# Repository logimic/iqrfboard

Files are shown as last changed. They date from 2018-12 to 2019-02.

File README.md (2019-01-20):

# [IQRFBB-10 Development Board](http://logimic.com/iqrfboard)


<br>
<br>
<p align="right">Powered for you by <a href="http://www.logimic.com" align="right">logimic.com</a></p>

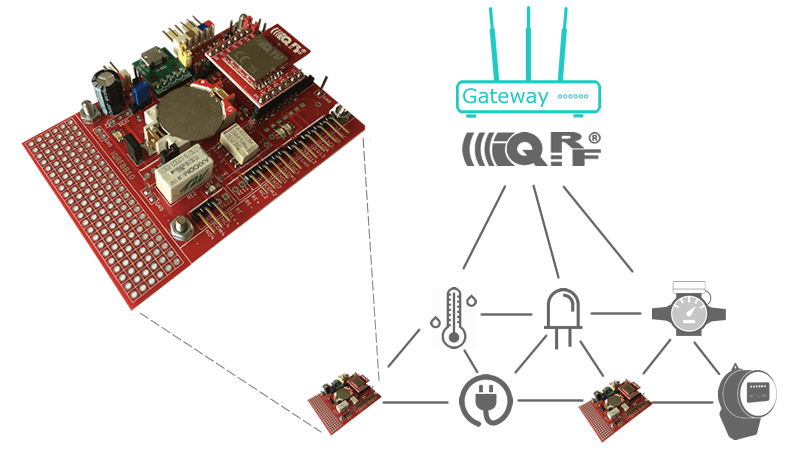
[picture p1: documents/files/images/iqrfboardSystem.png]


IQRF development board helps you to design IQRF wireless devices like sensors and actuators. Just connect sensors, load software and you get fully working IQRF prototype of device.

[Official project pages...](http://logimic.com/iqrfboard)

[Getting Started and Documentation pages...](http://logimic.com/iqrfboard/book/)

## Licensing

All content in the repository is licensed via the [MIT license](https://opensource.org/licenses/MIT)

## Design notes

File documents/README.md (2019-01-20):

# Getting Started with IQRFBB-10


IQRFBB-10 development board helps you to design IOT devices for IQRF wireless network. Simply connect sensor or actuator you want to, join the board to IQRF network and device is ready.
If you are satisfied with such working device scale IQRFBB-10 layout to final product and your IOT product is done.

In this tutorial we will show you:

* How to prepare IQRF network.
* How to connect IQRFBB-10 to the IQRF network as a node.
* How to connect different sensors to the board.
* How to communicate with the board from your software via IQRF gateway.

## Prepare IQRF network
Firs check IQRF network around you. If you do not have any, let's start with this tutorial [SetupIqrfNetwork](SetupIqrfNetwork.md).

## Assemble Board
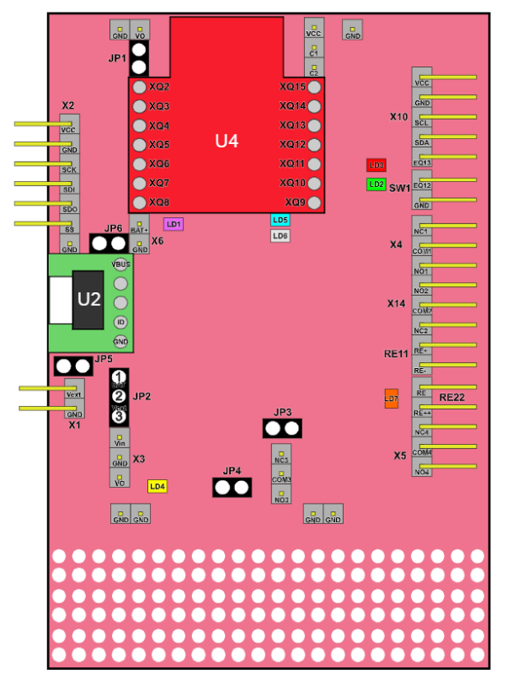
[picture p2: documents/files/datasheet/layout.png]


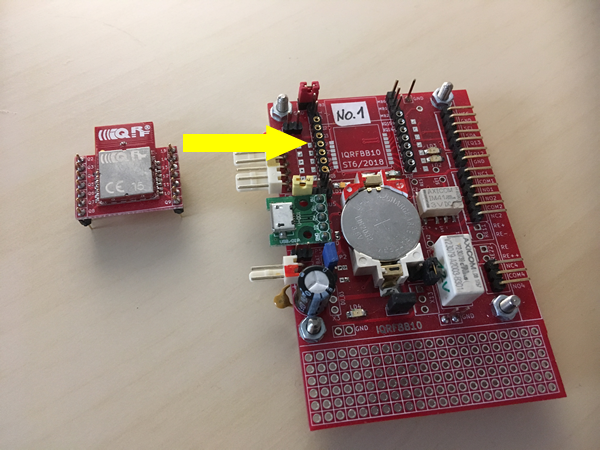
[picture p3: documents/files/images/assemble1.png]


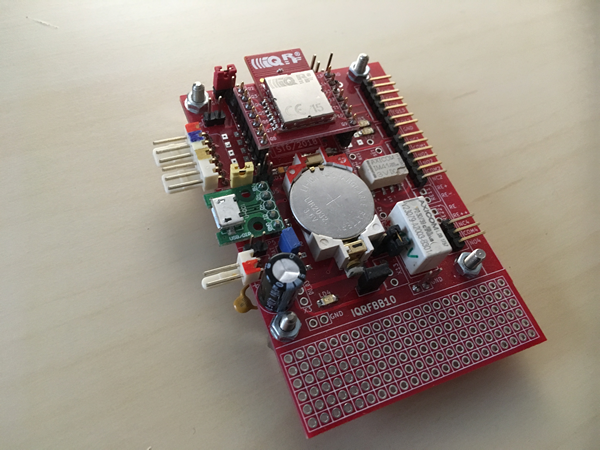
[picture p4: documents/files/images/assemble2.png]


* JP1: OFF
* JP6: OFF
* Insert IQRF TR into board

## Connect Programmer
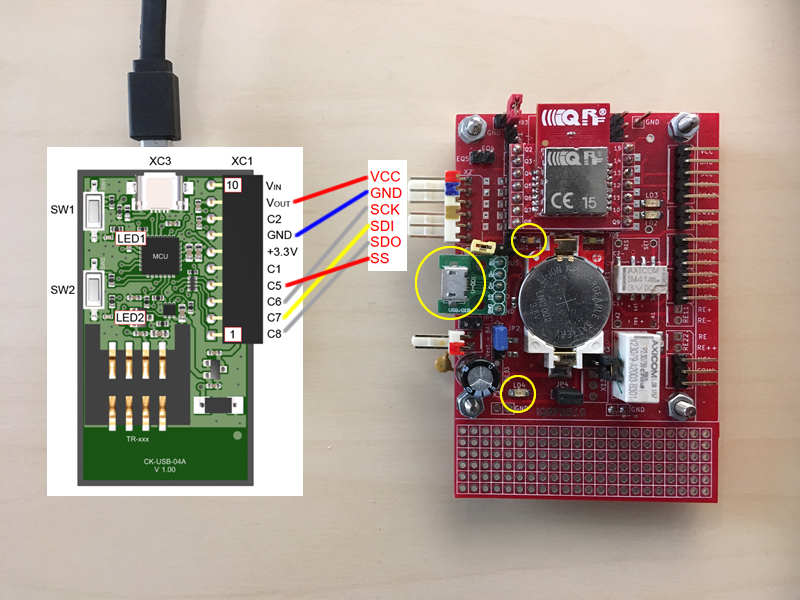
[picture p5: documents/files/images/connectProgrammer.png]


1. Unplug USB cable from CK-USB-04A

2. Unplug IQRFBB-10 from microUSB and JP6=OFF.

3. Unplug TR module JP1=OFF.

4. Make wiring

5. Plug JP4=ON, JP1=OFF.

6. Plug micro-USB to IQRFBB-10 to power-on. Indication LD1=ON (charging battery), LD4=ON

7. Plug micro-USB to CK-USB-04A

8. Now the board is ready for software loading

## Load Software
If we are talking about software loading, we always mean loading software to IQRF transceiver TR-76D mounted on IQRFBB-10. Via software load you configure transceiver within IQRF network. Now we will configure board (transceiver) as a node of IQRF network.

1. Make sure you made a proper wiring and both USB power sources (programmer + board) are on.

2. Now you can upload node configuration as described in [preparation of your IQRF network chapter](SetupIqrfNetwork.md#configure-nodes). **Do not put any IQRF module into CK-USB-04A programmer SIM!**

3. Uploading data into transciever is sihnalized by LD3 diod on IQRFBB-10 board.

4. Unplug micro USB of CK-USB-04A programmer

5. Unplug micro USB of IQRFBB-10 board.

6. Unplug CK-USB-04A from IQRFBB-10.

## Bond to Network
Bonding IQRF nodes is generally [described here...](SetupIqrfNetwork.md#run-network), bonding IQRFBB-10 board goes this way:

1. Turn on battery power **JP6 = ON**. Diod indicating power on is **LD4 = ON**.

2. Turn TR module power **JP1 = ON**.

3. Open IDE, then menu start Tools/IQMESH Network Manager and fill out the dialogue as shown (TX power, Auto address, ...).
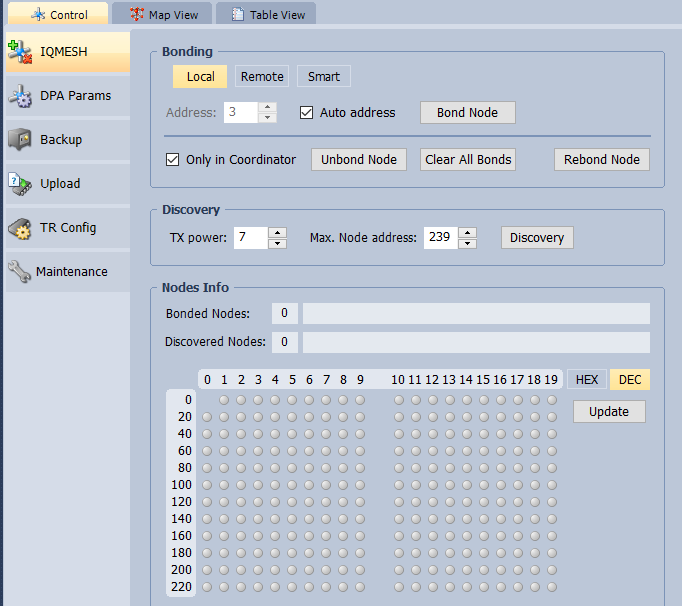
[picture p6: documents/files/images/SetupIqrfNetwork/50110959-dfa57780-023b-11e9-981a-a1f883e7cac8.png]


4. Then pres **Clear All Bonds** for remove any previous bonded modules. Red diods of modules are blinking, at IQRFBB-10 it is diod **LD3**.

5. Then pres **Bond Node** and during bonding period press and hold SW1 button at one node until green diod turns on. Repeat for each node. At IQRFBB-10 the SW1 is an external contact **EQ12, GND**, red diod is **LD3** and green diods is **LD2**.
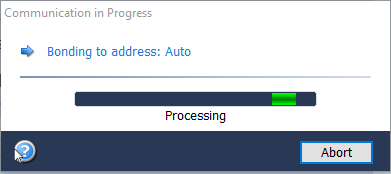
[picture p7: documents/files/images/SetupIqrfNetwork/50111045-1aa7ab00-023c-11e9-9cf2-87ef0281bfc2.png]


6. Now you should see yellow spots indicating successful bonding. Now click **Discovery** and spots are in blue.
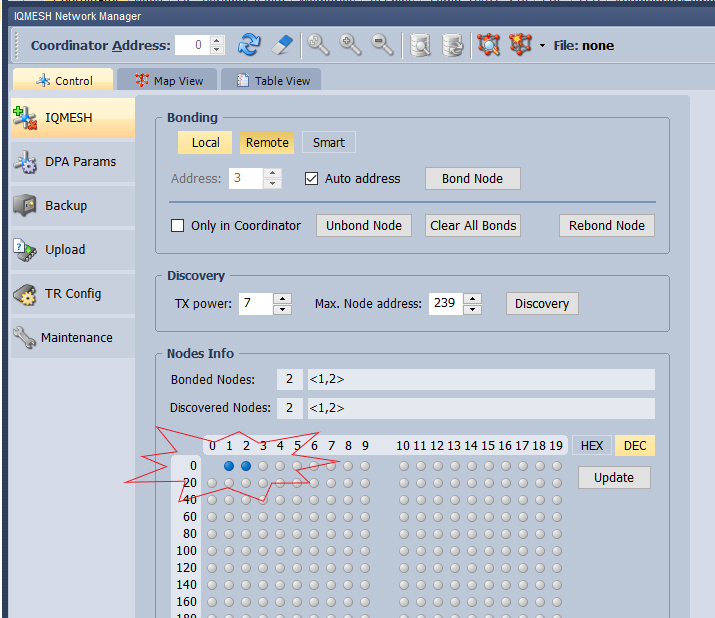
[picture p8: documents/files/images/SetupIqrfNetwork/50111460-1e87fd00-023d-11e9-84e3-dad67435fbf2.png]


7. Switch in IDE to **Map View** and you should see node structure something like in the picture.
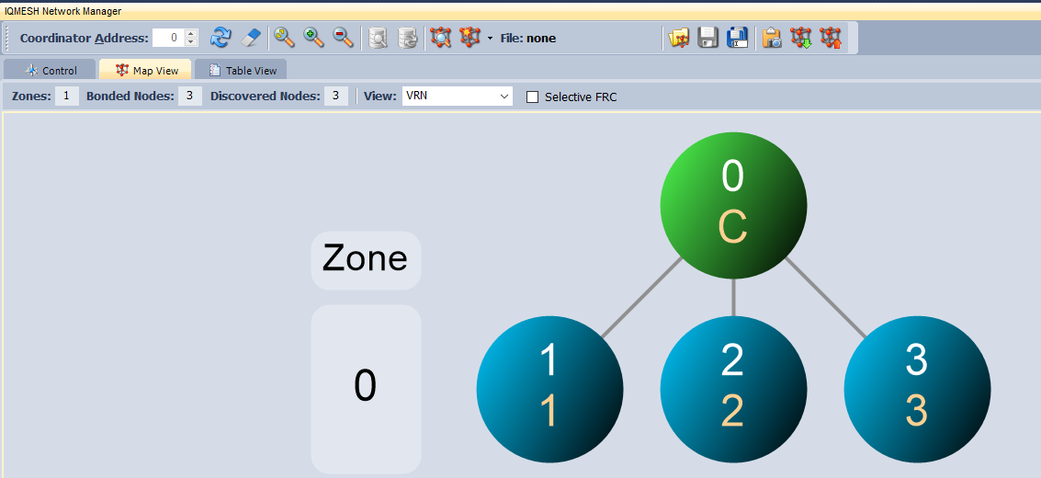
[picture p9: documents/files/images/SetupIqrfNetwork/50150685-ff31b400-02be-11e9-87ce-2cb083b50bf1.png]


8. Try to turn on **LD3 (RED diod)** on IQRFBB-10 board. Click rigt mouse button on spot indicating board (it depends on the bonding order) and select **LED Red On**. Then the **LD3 = ON** on the board.
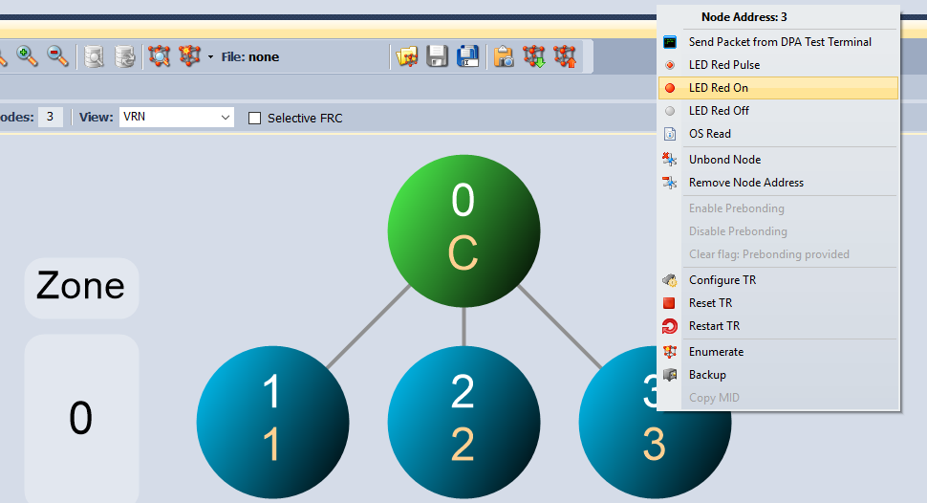
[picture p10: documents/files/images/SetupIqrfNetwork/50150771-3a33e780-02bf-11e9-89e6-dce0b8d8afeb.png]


## Check Operability
Now you have fully configured IQRFBB-10 board. You can check operability this way:

1. Battery power turn on/off is always done via **JP6**. When you power board on, then it is always automatically connected to the IQRF network (if you properly did all steps above).

2. For checking of connectivity open **IDE** and in **IQMESH Network Manager**, view **Control** click **Discovery** button. Working nodes are displayed in blue spots, previously bonded but inactive are shown as yellow spots.
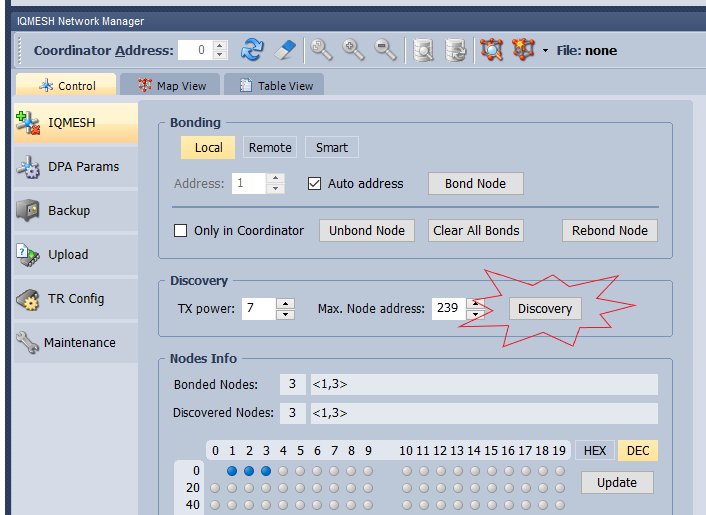
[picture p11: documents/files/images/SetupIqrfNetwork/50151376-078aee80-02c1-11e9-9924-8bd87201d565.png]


3. Switch to **Map View**, find IQRF-BB10 node (one of blue spheres) and try to turn on **LD3 (RED diod)** on IQRFBB-10 board. Right click mouse button on spot indicating board and select **LED Red On**. Then the **LD3 = ON** on the board.


## Examples
Now we can make from IQRFBB-10 any wireless sensor or actuator by wiring proper sensor or actuators. Let's continue to [our examples](Examples.md)

## Links
[Links](Links.md)

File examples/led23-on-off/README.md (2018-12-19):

# Set LED2, LED3 on/off

This example turns RED LED on, waits 2 seconds, then turns RED LED off and GREEN LED on, then after 2 seconds turns GREEN LED off.

## Prerequisities

1. **IQRFBB-10** bonded in working IQRF network. More in [GettingStarted with IQRFBB-10](https://github.com/logimic/iqrfboard/wiki)
2. **IQRF Gateway Daemon** working. More in [IQRF Gateway Daemon](https://github.com/logimic/iqrfboard/wiki/Get-IQRF-with-your-software#iqrf-gateway-daemon)
3. **Python 3.6 with WebSockets module**. More in [Python 3.6 WbSockets example](https://github.com/logimic/iqrfboard/wiki/Get-IQRF-with-your-software#python-36-websocket-example)

## Hardware wiring



No hardware wiring needed, both LED2 and LED3 are mounted on the board and connected to C1 and C2. See. [Documentation](https://github.com/logimic/iqrfboard/wiki/Getting-Started-with-IQRFBB-10#iqrfbb-10-documentation)

## Software

We use Standard DPA handler already loaded in board TR module.

### API JSON message

We can manage diods via sending [Daemon JSON API](https://docs.iqrfsdk.org/iqrf-gateway-daemon/) messages.

* LD2 (Green DIOD) ON/OFF
  * [Set LEDG request v1-0-0](https://apidocs.iqrf.org/iqrf-gateway-daemon/json/#iqrf/iqrfEmbedLedg_Set-request-1-0-0.json), [..example](https://apidocs.iqrf.org/iqrf-gateway-daemon/json/iqrf/examples/iqrfEmbedLedg_Set-request-1-0-0-example.json)
  * [Set LEDG response v1-0-0](https://apidocs.iqrf.org/iqrf-gateway-daemon/json/#iqrf/iqrfEmbedLedr_Set-response-1-0-0.json), [..example](https://apidocs.iqrf.org/iqrf-gateway-daemon/json/iqrf/examples/iqrfEmbedLedr_Set-response-1-0-0-example.json)

* LD3 (Red DIOD) ON/OFF
  * [Set LEDR request v1-0-0](https://apidocs.iqrf.org/iqrf-gateway-daemon/json/#iqrf/iqrfEmbedLedr_Set-request-1-0-0.json), [..example](https://apidocs.iqrf.org/iqrf-gateway-daemon/json/iqrf/examples/iqrfEmbedLedr_Set-request-1-0-0-example.json)
  * [Set LEDR response v1-0-0](https://apidocs.iqrf.org/iqrf-gateway-daemon/json/#iqrf/iqrfEmbedLedr_Set-response-1-0-0.json), [..example](https://apidocs.iqrf.org/iqrf-gateway-daemon/json/iqrf/examples/iqrfEmbedLedr_Set-response-1-0-0-example.json)

### Testing Software

The [led23-on-off.py](led23-on-off.py) script also prints sent and received JSON messages

```py
#
# Copyright 2018 Logimic,s.r.o.
# www.logimic.com
#
# Licensed under the Apache License, Version 2.0 (the "License");
# you may not use this file except in compliance with the License.
# You may obtain a copy of the License at
#
#     http://www.apache.org/licenses/LICENSE-2.0
#
# Unless required by applicable law or agreed to in writing, software
# distributed under the License is distributed on an "AS IS" BASIS,
# WITHOUT WARRANTIES OR CONDITIONS OF ANY KIND, either express or implied.
# See the License for the specific language governing permissions and
# limitations under the License.
#

# Websockets led-on-off.py
import asyncio
import websockets
import json
import time

# This is IQRFBB-10 node address in IQRF network
boardAddr = 3

# JSON messages by "https://docs.iqrfsdk.org/iqrf-gateway-daemon/api.html"
LEDR_ON = {
  "mType": "iqrfEmbedLedr_Set",
  "data": {
    "msgId": "testEmbedLedr",
    "req": {
      "nAdr": boardAddr,
      "param": {
        "onOff": True
      }
    },
    "returnVerbose": True
  }
}

LEDR_OFF = {
  "mType": "iqrfEmbedLedr_Set",
  "data": {
    "msgId": "testEmbedLedr",
    "req": {
      "nAdr": boardAddr,
      "param": {
        "onOff": False
      }
    },
    "returnVerbose": True
  }
}

LEDG_ON = {
  "mType": "iqrfEmbedLedg_Set",
  "data": {
    "msgId": "testEmbedLedr",
    "req": {
      "nAdr": boardAddr,
      "param": {
        "onOff": True
      }
    },
    "returnVerbose": True
  }
}

LEDG_OFF = {
  "mType": "iqrfEmbedLedg_Set",
  "data": {
    "msgId": "testEmbedLedr",
    "req": {
      "nAdr": boardAddr,
      "param": {
        "onOff": False
      }
    },
    "returnVerbose": True
  }
}

async def hello():
    # Connect websockets
    async with websockets.connect(
            'ws://localhost:1338') as websocket:

        # RED LED ON
        await websocket.send(json.dumps(LEDR_ON))
        print(f"Sent > {LEDR_ON}")

        response = await websocket.recv()
        print(f"Received < {response}")

        # Wait 2 sec
        time.sleep(2)

        # RED LED OFF
        await websocket.send(json.dumps(LEDR_OFF))
        print(f"Sent > {LEDR_OFF}")

        response = await websocket.recv()
        print(f"Received < {response}")        

        # GREEN LED ON
        await websocket.send(json.dumps(LEDG_ON))
        print(f"Sent > {LEDG_ON}")

        response = await websocket.recv()
        print(f"Received < {response}")        

        # Wait 2 sec
        time.sleep(2)

        # GREEN LED OFF
        await websocket.send(json.dumps(LEDG_OFF))
        print(f"Sent > {LEDG_OFF}")

        response = await websocket.recv()
        print(f"Received < {response}")            

asyncio.get_event_loop().run_until_complete(hello())
```

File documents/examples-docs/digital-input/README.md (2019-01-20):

# Digital Input

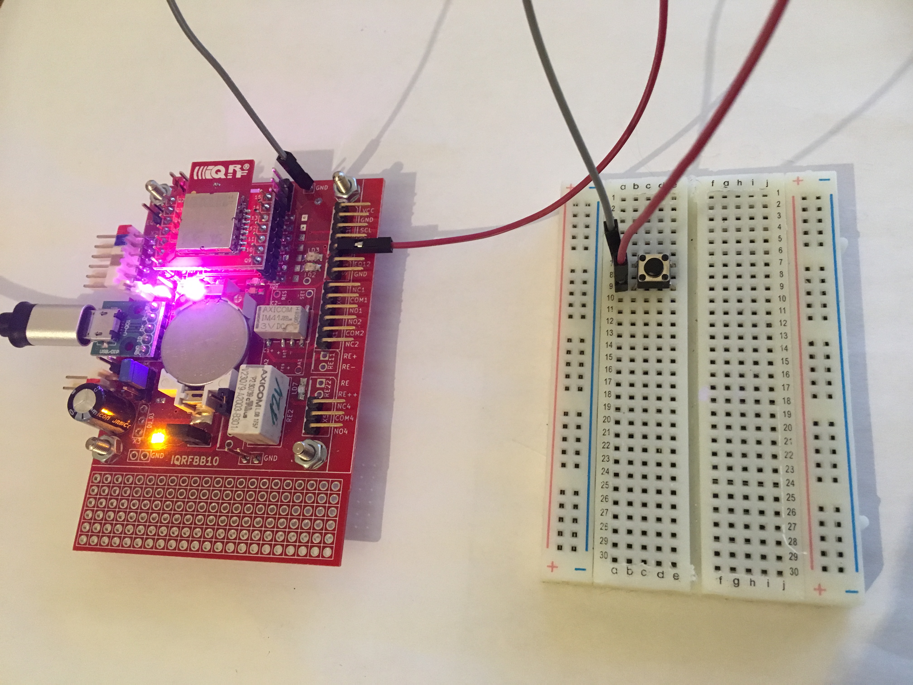
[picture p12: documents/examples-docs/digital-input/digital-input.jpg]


This example shows how to detect DI on board. We will detect connection EQ13 pin to GRND. DI status is tested by testing software via reading all inputs.

## Prerequisities

1. **IQRFBB-10** bonded in working IQRF network. More in [GettingStarted with IQRFBB-10](https://github.com/logimic/iqrfboard/wiki)
2. **IQRF Gateway Daemon** running. More in [IQRF Gateway Daemon](https://github.com/logimic/iqrfboard/wiki/IQRF-Gateway-Daemon)
3. **Python 3.6 with WebSockets module**. More in [Python 3.6 WbSockets example](https://github.com/logimic/iqrfboard/wiki/Get-IQRF-with-your-software#python-36-websocket-example)

## Hardware wiring



_Fig.: IQRFBB10 schema_

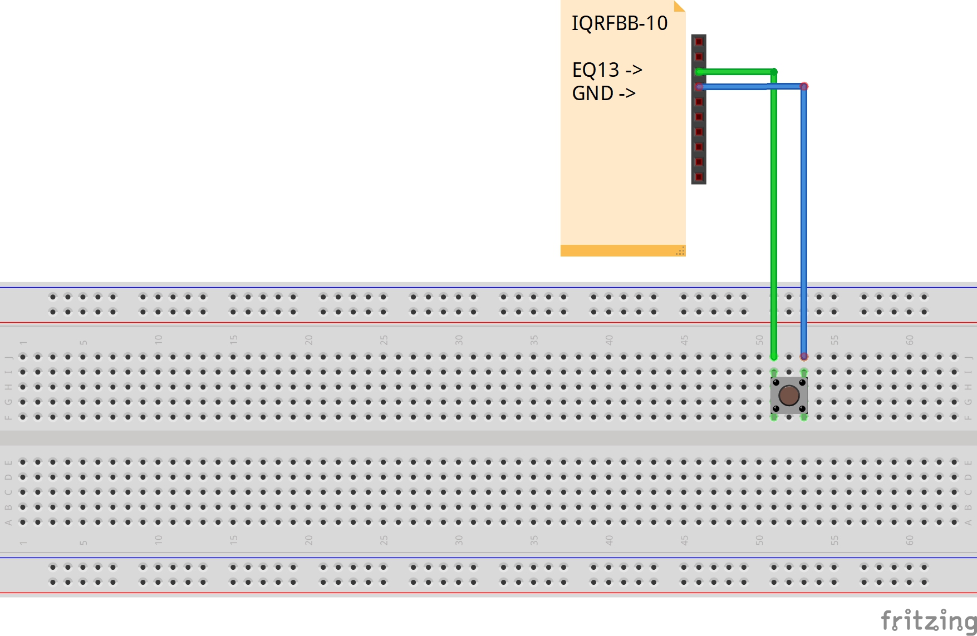
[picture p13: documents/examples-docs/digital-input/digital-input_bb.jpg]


_Fig.: External LED wiring_

Connect EQ13 and GRND pins via button.

## Software

* We use Standard DPA handler already loaded in board TR module.
* Testing software:
  - Set EQ13 as DI. EQ13 is **Q13/RE3** pin on TR-76DA.
  - Ask user to press an hold button
  - Wait 3sec
  - Read all DI
  - Parse response and make decision

### API JSON message

We will use pure DPA messages handled via [Daemon JSON API](https://docs.iqrfsdk.org/iqrf-gateway-daemon/):

* [RawHdp request  v1-0-0](https://apidocs.iqrf.org/iqrf-gateway-daemon/json/#iqrf/iqrfRawHdp-request-1-0-0.json), [..example](https://apidocs.iqrf.org/iqrf-gateway-daemon/json/iqrf/examples/iqrfRawHdp-request-1-0-0-example.json)
* [RawHdp response  v1-0-0](https://apidocs.iqrf.org/iqrf-gateway-daemon/json/#iqrf/iqrfRawHdp-response-1-0-0.json), [..example](https://apidocs.iqrf.org/iqrf-gateway-daemon/json/iqrf/examples/iqrfRawHdp-response-1-0-0-example.json)

**DPA commands:**

| NADR | PNUM | PCMD | HWPID |  PDATA | What |
|:----:|:----:|:----:|:-----:|:---:| --- |
| XXXX |  09  |  00  | FFFF  | 10.08.08 | Set RE3 (Address E3) as DI |
| XXXX |  09  |  02  | FFFF  | | Read all DI pins |

* _NADR: must be your address of IQRFBB-10 in IQRF network._
* _Numbers in table are in hex format._

### Testing Software

The [digital-input.py](https://github.com/logimic/iqrfboard/blob/master/examples/digital-input.py).

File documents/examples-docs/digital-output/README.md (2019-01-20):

# Digital Output

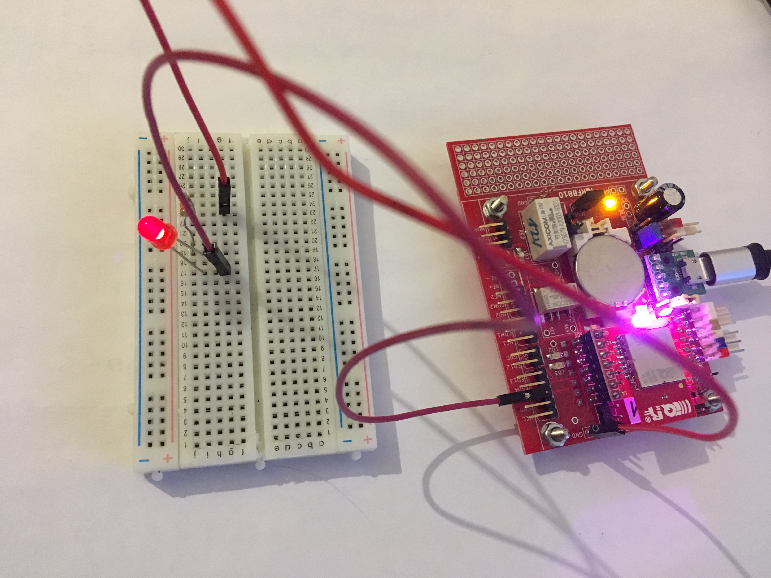
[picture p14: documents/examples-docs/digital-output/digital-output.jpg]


This example shows how to set EQ6 (X10 SCL) pin of the board.

## Prerequisities

1. **IQRFBB-10** bonded in working IQRF network. More in [Getting Started](../../README.md)
2. **IQRF Gateway Daemon** working. More in [IQRF Gateway Daemon](../../IqrfGatewayDaemon.md)
3. **Python 3.6 with WebSockets module**. More in [Python WebSockets example](../../IqrfGatewayDaemon.md#python-websocket-example)

## Hardware wiring



_Fig.: IQRFBB10 schema_

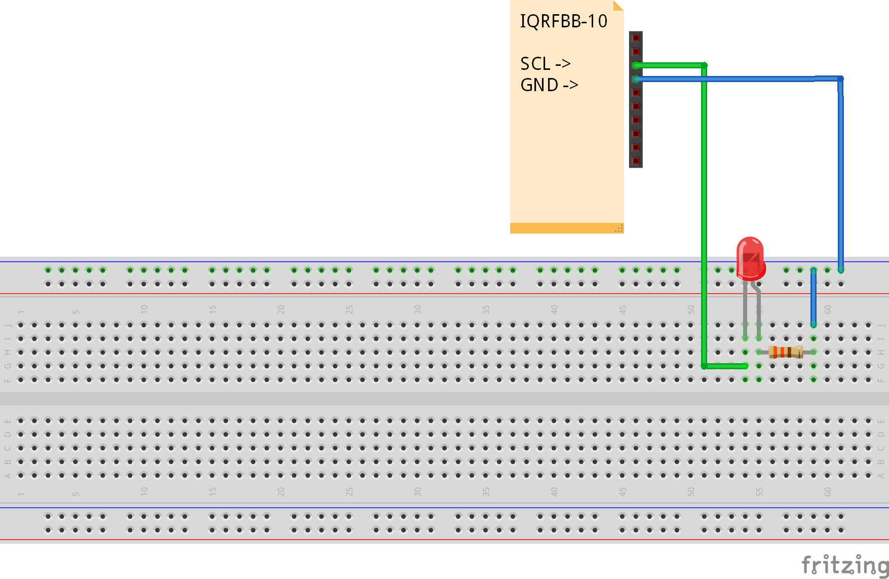
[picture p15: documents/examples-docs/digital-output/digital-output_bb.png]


_Fig.: External LED wiring_

Connect SCL and GRN pins via button.

## Software

* We use Standard DPA handler already loaded in board TR module.
* Testing software:
  - Set EQ6 (X10 SCL) as DO. EQ6 is **Q6, C6/RC3** genral I/O pin on TR-76DA.
  - Set pin HI
  - Wait 3sec
  - Set pin LO

### API JSON message

We will use DPA messages handled via [Daemon JSON API](https://docs.iqrfsdk.org/iqrf-gateway-daemon/):

* [RawHdp request  v1-0-0](https://apidocs.iqrf.org/iqrf-gateway-daemon/json/#iqrf/iqrfRawHdp-request-1-0-0.json), [..example](https://apidocs.iqrf.org/iqrf-gateway-daemon/json/iqrf/examples/iqrfRawHdp-request-1-0-0-example.json)
* [RawHdp response  v1-0-0](https://apidocs.iqrf.org/iqrf-gateway-daemon/json/#iqrf/iqrfRawHdp-response-1-0-0.json), [..example](https://apidocs.iqrf.org/iqrf-gateway-daemon/json/iqrf/examples/iqrfRawHdp-response-1-0-0-example.json)

**DPA commands:**

| NADR | PNUM | PCMD | HWPID |  PDATA | What |
|:----:|:----:|:----:|:-----:|:---:| --- |
| XXXX |  09  |  00  | FFFF  | 02.08.00 | Set RC3 (Address C3) as D0 |
| XXXX |  09  |  01  | FFFF  | 02.08.08 | Set pin HI |
| XXXX |  09  |  01  | FFFF  | 02.08.00 | Set pin LO |

* _NADR: must be your address of IQRFBB-10 in IQRF network._
* _Numbers in table are in hex format._

### Testing Software

The [digital-output.py](https://github.com/logimic/iqrfboard/blob/master/examples/digital-output.py).

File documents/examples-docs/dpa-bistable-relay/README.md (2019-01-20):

# Bi-stable relay

This example turns bistable relay on/off.

## Prerequisities

1. **IQRFBB-10** bonded in working IQRF network. More in [GettingStarted with IQRFBB-10](https://github.com/logimic/iqrfboard/wiki)
2. **IQRF Gateway Daemon** running. More in [IQRF Gateway Daemon](https://github.com/logimic/iqrfboard/wiki/IQRF-Gateway-Daemon)
3. **Python 3.6 with WebSockets module**. More in [Python 3.6 WbSockets example](https://github.com/logimic/iqrfboard/wiki/Get-IQRF-with-your-software#python-36-websocket-example)

## Hardware wiring



No hardware wiring needed, bistable relay is managed via C1 and C2 signals. See. [Documentation](https://github.com/logimic/iqrfboard/wiki/Getting-Started-with-IQRFBB-10#iqrfbb-10-documentation)

## Software

* We use Standard DPA handler already loaded in board TR module.
* Testing software:
  - Set EQ14 as DO. EQ14 is **Q14/C1/RA0** pin on TR-76DA.
  - Set EQ15 as DO. EQ15 is **Q15/C2/RC2** pin on TR-76DA.
  - Set C2=LO, C1=HI
  - Wait 3secs
  - Set C2=HI, C1=LO

### API JSON message

We will use pure DPA messages handled via [Daemon JSON API](https://docs.iqrfsdk.org/iqrf-gateway-daemon/):

* [RawHdp request  v1-0-0](https://apidocs.iqrf.org/iqrf-gateway-daemon/json/#iqrf/iqrfRawHdp-request-1-0-0.json), [..example](https://apidocs.iqrf.org/iqrf-gateway-daemon/json/iqrf/examples/iqrfRawHdp-request-1-0-0-example.json)
* [RawHdp response  v1-0-0](https://apidocs.iqrf.org/iqrf-gateway-daemon/json/#iqrf/iqrfRawHdp-response-1-0-0.json), [..example](https://apidocs.iqrf.org/iqrf-gateway-daemon/json/iqrf/examples/iqrfRawHdp-response-1-0-0-example.json)

**DPA commands:**

| NADR | PNUM | PCMD | HWPID |  PDATA | What |
|:----:|:----:|:----:|:-----:|:---:| --- |
| XXXX |  09  |  00  | - | 00.01.00 | Set C1 Output |
| XXXX |  09  |  00  | - | 02.04.00 | Set C2 Output |
| XXXX |  09  |  01  | - | 00.01.01 | Set C1 ON |
| XXXX |  09  |  01  | - | 00.01.00 | Set C1 OFF |
| XXXX |  09  |  01  | - | 02.04.04 | Set C2 ON |
| XXXX |  09  |  01  | - | 02.04.00 | Set C2 OFF |

* _NADR: must be your address of IQRFBB-10 in IQRF network._
* _Numbers in table are in hex format._

### Testing Software

The [dpa-bistable-relay.py](https://github.com/logimic/iqrfboard/blob/master/examples/dpa-bistable-relay.py) script.

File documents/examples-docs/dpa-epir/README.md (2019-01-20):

# Motion Sensor (ePir)

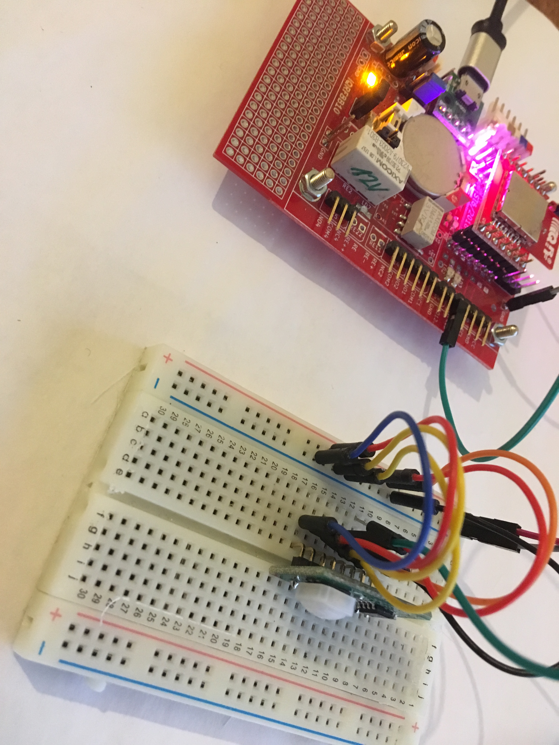
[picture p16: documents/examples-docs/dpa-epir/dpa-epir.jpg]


This example shows how to connect [Zilog ePIR – SparkFub – SEN-09587](https://www.sparkfun.com/datasheets/Sensors/Proximity/SEN-09587-PS0284.pdf) to the board.

## Prerequisities

1. **IQRFBB-10** bonded in working IQRF network. More in [GettingStarted with IQRFBB-10](https://github.com/logimic/iqrfboard/wiki)
2. **IQRF Gateway Daemon** running. More in [IQRF Gateway Daemon](https://github.com/logimic/iqrfboard/wiki/IQRF-Gateway-Daemon)
3. **Python 3.6 with WebSockets module**. More in [Python 3.6 WbSockets example](https://github.com/logimic/iqrfboard/wiki/Get-IQRF-with-your-software#python-36-websocket-example)

## Hardware wiring



_Fig.: IQRFBB10 schema_

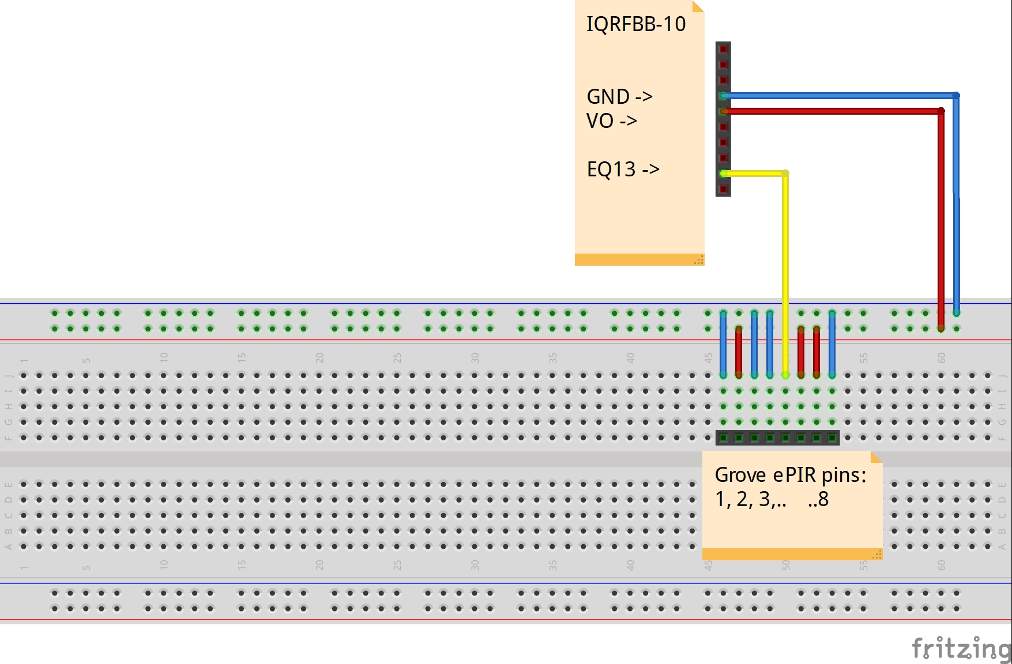
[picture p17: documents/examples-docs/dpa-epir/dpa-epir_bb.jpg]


_Fig.: External LED wiring_

Connect VO, EQ13 and GRND pins with [Zilog ePIR – SparkFub – SEN-09587](https://www.sparkfun.com/datasheets/Sensors/Proximity/SEN-09587-PS0284.pdf).

## Software

* We use Standard DPA handler already loaded in board TR module.
* Testing software:
    - Set EQ13 as DI. EQ13 is **Q13/RE3** pin on TR-76DA.
    - Read all DI in the loop
        - Parse response and make decision

### API JSON message

We will use pure DPA messages handled via [Daemon JSON API](https://docs.iqrfsdk.org/iqrf-gateway-daemon/):

* [RawHdp request  v1-0-0](https://apidocs.iqrf.org/iqrf-gateway-daemon/json/#iqrf/iqrfRawHdp-request-1-0-0.json), [..example](https://apidocs.iqrf.org/iqrf-gateway-daemon/json/iqrf/examples/iqrfRawHdp-request-1-0-0-example.json)
* [RawHdp response  v1-0-0](https://apidocs.iqrf.org/iqrf-gateway-daemon/json/#iqrf/iqrfRawHdp-response-1-0-0.json), [..example](https://apidocs.iqrf.org/iqrf-gateway-daemon/json/iqrf/examples/iqrfRawHdp-response-1-0-0-example.json)

**DPA commands:**

| NADR | PNUM | PCMD | HWPID |  PDATA | What |
|:----:|:----:|:----:|:-----:|:---:| --- |
| XXXX |  09  |  00  | FFFF  | 10.08.08 | Set RE3 (Address E3) as DI |
| XXXX |  09  |  02  | FFFF  | | Read all DI pins |

* _NADR: must be your address of IQRFBB-10 in IQRF network._
* _Numbers in table are in hex format._

### Testing Software

The link [dpa-epir.py](https://github.com/logimic/iqrfboard/blob/master/examples/dpa-epir.py).

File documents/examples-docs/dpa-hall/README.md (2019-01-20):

# Hall Magnetic Sensor

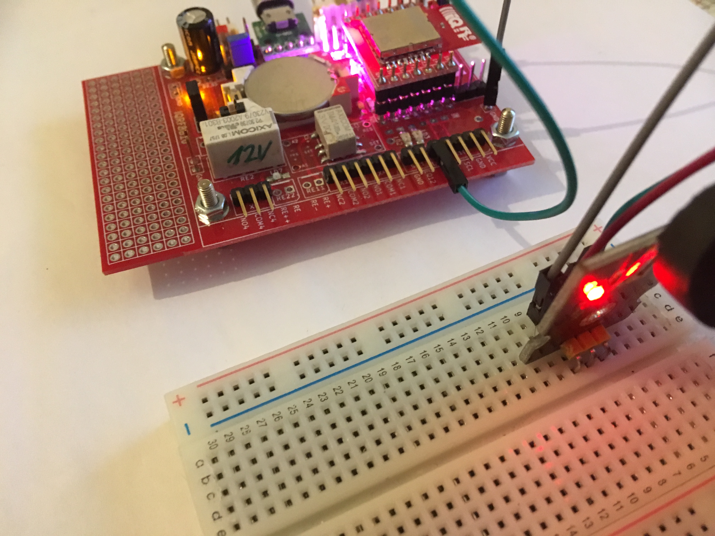
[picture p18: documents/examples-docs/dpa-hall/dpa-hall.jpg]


This example shows how to connect [KS0020 Hall Magnetic Sensor](http://wiki.keyestudio.com/index.php/Ks0020_keyestudio_Hall_Magnetic_Sensor) with the board.

## Prerequisities

1. **IQRFBB-10** bonded in working IQRF network. More in [GettingStarted with IQRFBB-10](https://github.com/logimic/iqrfboard/wiki)
2. **IQRF Gateway Daemon** running. More in [IQRF Gateway Daemon](https://github.com/logimic/iqrfboard/wiki/IQRF-Gateway-Daemon)
3. **Python 3.6 with WebSockets module**. More in [Python 3.6 WbSockets example](https://github.com/logimic/iqrfboard/wiki/Get-IQRF-with-your-software#python-36-websocket-example)

## Hardware wiring



_Fig.: IQRFBB10 schema_

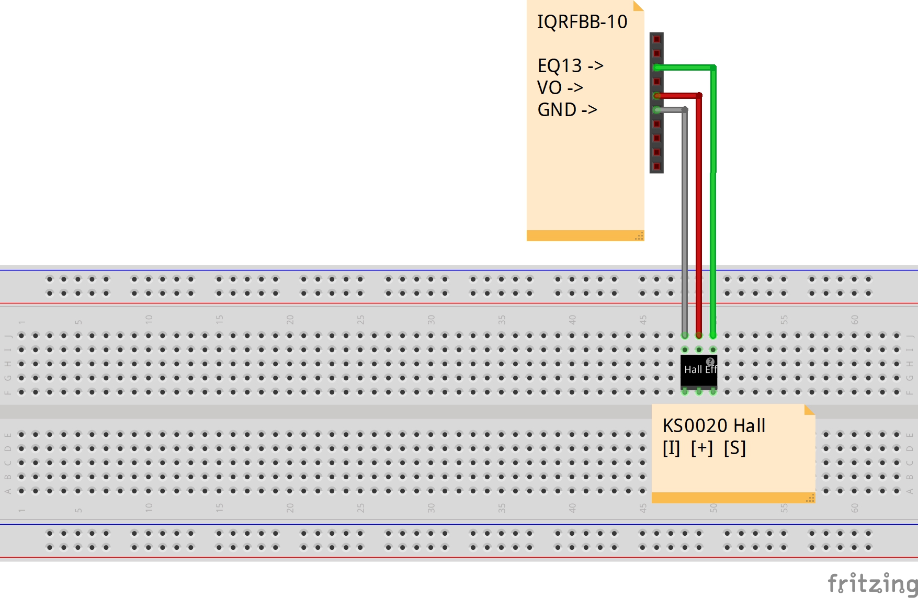
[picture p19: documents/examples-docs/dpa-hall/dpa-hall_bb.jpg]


_Fig.: External LED wiring_

Connect VO, EQ13 and GRND pins with [KS0020 Keyestudio Hall Magnetic Sensor](http://wiki.keyestudio.com/index.php/Ks0020_keyestudio_Hall_Magnetic_Sensor).

## Software

* We use Standard DPA handler already loaded in board TR module.
* Testing software:
  - Set EQ13 as DI. EQ13 is **Q13/RE3** pin on TR-76DA.
  - Read all DI in the loop
  - Parse response and make decision

### API JSON message

We will use pure DPA messages handled via [Daemon JSON API](https://docs.iqrfsdk.org/iqrf-gateway-daemon/):

* [RawHdp request  v1-0-0](https://apidocs.iqrf.org/iqrf-gateway-daemon/json/#iqrf/iqrfRawHdp-request-1-0-0.json), [..example](https://apidocs.iqrf.org/iqrf-gateway-daemon/json/iqrf/examples/iqrfRawHdp-request-1-0-0-example.json)
* [RawHdp response  v1-0-0](https://apidocs.iqrf.org/iqrf-gateway-daemon/json/#iqrf/iqrfRawHdp-response-1-0-0.json), [..example](https://apidocs.iqrf.org/iqrf-gateway-daemon/json/iqrf/examples/iqrfRawHdp-response-1-0-0-example.json)

**DPA commands:**

| NADR | PNUM | PCMD | HWPID |  PDATA | What |
|:----:|:----:|:----:|:-----:|:---:| --- |
| XXXX |  09  |  00  | FFFF  | 10.08.08 | Set RE3 (Address E3) as DI |
| XXXX |  09  |  02  | FFFF  | | Read all DI pins |

* _NADR: must be your address of IQRFBB-10 in IQRF network._
* _Numbers in table are in hex format._

### Testing Software

Link to [dpa-hall.py](https://github.com/logimic/iqrfboard/blob/master/examples/dpa-hall.py).

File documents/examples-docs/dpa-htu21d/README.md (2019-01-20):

# Temperature & Humidity Sensor

This example shows how to connect [HTU21D](http://wiki.keyestudio.com/index.php/Ks0020_keyestudio_Hall_Magnetic_Sensor) with the board and measure temperature and humidity.

## Links

* [HTU21D Datasheet](https://www.te.com/commerce/DocumentDelivery/DDEController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)

## Prerequisities

1. **IQRFBB-10** bonded in working IQRF network. More in [GettingStarted with IQRFBB-10](https://github.com/logimic/iqrfboard/wiki)
2. **IQRF Gateway Daemon** running. More in [IQRF Gateway Daemon](https://github.com/logimic/iqrfboard/wiki/IQRF-Gateway-Daemon)
3. **Python 3.6 with WebSockets module**. More in [Python 3.6 WbSockets example](https://github.com/logimic/iqrfboard/wiki/Get-IQRF-with-your-software#python-36-websocket-example)

## Hardware wiring



_Fig. IQRFBB10 schema_

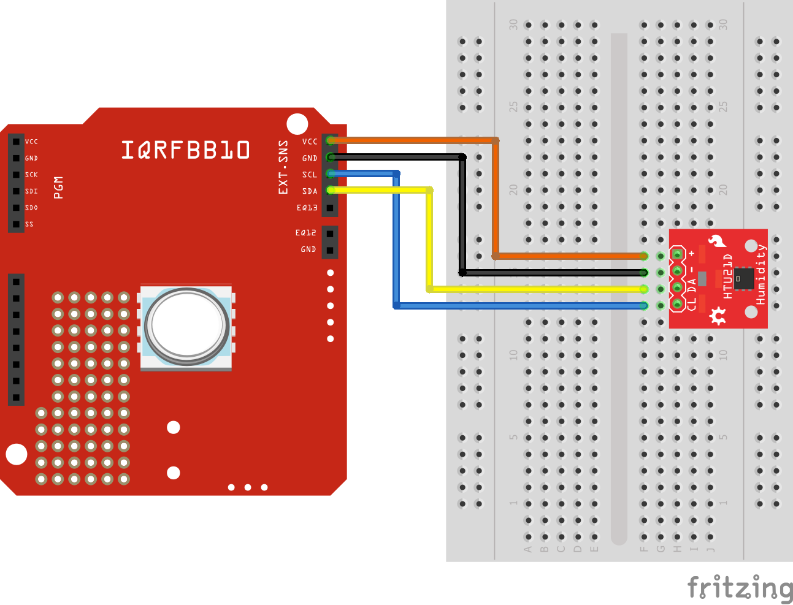
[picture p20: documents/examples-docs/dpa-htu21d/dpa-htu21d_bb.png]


_Fig. External LED wiring_

## Software

### Custom DPA Handler

We use Custom DPA Handler [dpa-htu21d.c](https://github.com/logimic/iqrfboard/blob/master/examples/dpa-htu21d.c) in this repo. Copy the file into IQRF SDK folders and load to TR module as [described here](../../SetupIqrfNetwork.md#load-custom-dpa-handler).

### API JSON message

We will use pure DPA messages handled via [Daemon JSON API](https://docs.iqrfsdk.org/iqrf-gateway-daemon/):

* [RawHdp request  v1-0-0](https://apidocs.iqrf.org/iqrf-gateway-daemon/json/#iqrf/iqrfRawHdp-request-1-0-0.json), [..example](https://apidocs.iqrf.org/iqrf-gateway-daemon/json/iqrf/examples/iqrfRawHdp-request-1-0-0-example.json)
* [RawHdp response  v1-0-0](https://apidocs.iqrf.org/iqrf-gateway-daemon/json/#iqrf/iqrfRawHdp-response-1-0-0.json), [..example](https://apidocs.iqrf.org/iqrf-gateway-daemon/json/iqrf/examples/iqrfRawHdp-response-1-0-0-example.json)

**DPA commands:**

| NADR | PNUM | PCMD | HWPID | PDATA | What |
|:----:|:----:|:----:|:-----:|:-----:| --- |
| XXXX | 0x20 |  00  | - | | Get user periphery status |

* _NADR: must be your address of IQRFBB-10 in IQRF network._
* _Numbers in table are in hex format._

### Testing Software

The link [dpa-htu21d.py](https://github.com/logimic/iqrfboard/blob/master/examples/dpa-htu21d.py).

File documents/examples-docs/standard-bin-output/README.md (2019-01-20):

# Standard Binary Output

This example shows how to create "Standard Binary Output" e.g. relay which will be  immediately recognized and manageable from IOT world thanks to gateways and standardization.

Standardization does not limit your hardware creativity, your binary output can be relay, LED, or whatever else. In following example we will implement 5 binary outputs on the one board. They will control LED2, LED3, bi-stable relay (2 binary outputs needed) and one external LED.

## Prerequisities

1. **IQRFBB-10** bonded in working IQRF network. More in [Getting Started](../../README.md)
2. **IQRF Gateway Daemon** working. More in [IQRF Gateway Daemon](../../IqrfGatewayDaemon.md)
3. **Python 3.6 with WebSockets module**. More in [Python WebSockets example](../../IqrfGatewayDaemon.md#python-websocket-example)

## Hardware wiring





Here is wiring of external LED connected to SCL/EX6 pin.

## Software in TR module

The [standard-bin-output.c](https://github.com/logimic/iqrfboard/blob/master/examples/standard-bin-output.c) implements five binary outputs.
Please load this "Custom DPA Handler" to TR module on board. [Load Custom DPA Handler](../../SetupIqrfNetwork.md#load-custom-dpa-handler) manual.

## API JSON message

Since we implemented standard binary output we can use all standardized JSON messages for [Binary Output ](https://docs.iqrfsdk.org/iqrf-gateway-daemon/api.html#binaryoutput) via JSON API of gateways.

## Testing Python code

The [standard-bin-output.py](https://github.com/logimic/iqrfboard/blob/master/examples/standard-bin-output.py) does following:

- Gets number of implemented binary outputs in TR module.
- LED2 = ON
- LED2 = OF, - LED3 = ON
- LED3 = OFF
- bi-stable relay = ON
- bi-stable relay = OFF
- External LED = ON
- External LED = OFF

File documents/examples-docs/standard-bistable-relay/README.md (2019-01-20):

# Standard Bi-stable Relay

This example shows how to manage bi-stable relay on board via standard messages. Bi-stable relay is designed on board and is driven by two digital outputs C1 and C0. Relay state is shown via LD5 and LD6 diod.

## Prerequisities

1. **IQRFBB-10** bonded in working IQRF network. More in [Getting Started](../../README.md)
2. **IQRF Gateway Daemon** working. More in [IQRF Gateway Daemon](../../IqrfGatewayDaemon.md)
3. **Python 3.6 with WebSockets module**. More in [Python WebSockets example](../../IqrfGatewayDaemon.md#python-websocket-example)

## Hardware wiring



No special wiring since the relay is on the board. The state of relay is signalized via LD5 and LD6 or you can connect any external cicuit to relay contacts NC1, COM1, NO1 and NC2, COM2, NO2. See drawings.   

## Software in TR module

The [standard-bistable-relay.c](https://github.com/logimic/iqrfboard/blob/master/examples/standard-bistable-relay.c) implements two binary outputs.
Please load this "Custom DPA Handler" to TR module on board. [Load Custom DPA Handler](../../SetupIqrfNetwork.md#load-custom-dpa-handler) manual.

## API JSON message

Since we implemented standard binary output we can use all standardized JSON messages for [Binary Output ](https://docs.iqrfsdk.org/iqrf-gateway-daemon/api.html#binaryoutput) via JSON API of gateways.

## Testing Python code

The [standard-bistable-relay.py](https://github.com/logimic/iqrfboard/blob/master/examples/standard-bistable-relay.py) does following:

- Gets number of implemented binary outputs in TR module.
- 3 times switches state of bi-stable relay.

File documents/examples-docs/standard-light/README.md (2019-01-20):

# Standard Light

This example shows how to create "Standard light" which means that entire world will know that your device is just a light and will be able to manage it (turn on/off, dim, get status and more). This is possible thanks to standardized API and IQRF gateways.

Standardization does not limit your hardware creativity, your light can be whatever you connect. The software in TR module makes connection with API.

In following we will show how to implement three lights on the one board. The lights will be LED2, LED3 and external LED on SCL/EQ6 PIN.

## Prerequisities

1. **IQRFBB-10** bonded in working IQRF network. More in [Getting Started](../../README.md)
2. **IQRF Gateway Daemon** working. More in [IQRF Gateway Daemon](../../IqrfGatewayDaemon.md)
3. **Python 3.6 with WebSockets module**. More in [Python WebSockets example](../../IqrfGatewayDaemon.md#python-websocket-example)

## Hardware wiring





Connect external LED to SCL/EQ6 PIN.

## Software in TR module

The [standard-light.c](https://github.com/logimic/iqrfboard/blob/master/examples/standard-light.c) implements three lights on LED2, LED3 and SCL/EQ6 outputs.
Please load this "Custom DPA Handler" to TR module on board. [Load Custom DPA Handler](../../SetupIqrfNetwork.md#load-custom-dpa-handler) manual.

## API JSON message

Since we implemented standard light we can use standardized JSON messages for [management of Lights](https://docs.iqrfsdk.org/iqrf-gateway-daemon/api.html#light) via JSON API of gateways.

## Testing Python code

The [standard-light.py](https://github.com/logimic/iqrfboard/blob/master/examples/standard-light.py) does:

- LED3=ON
- LED3=OFF, LED2=ON
- LED2=OFF, ext. LED=ON
- ext. LED=OFF

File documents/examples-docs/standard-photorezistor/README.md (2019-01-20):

# Standard Photorezistor Sensor

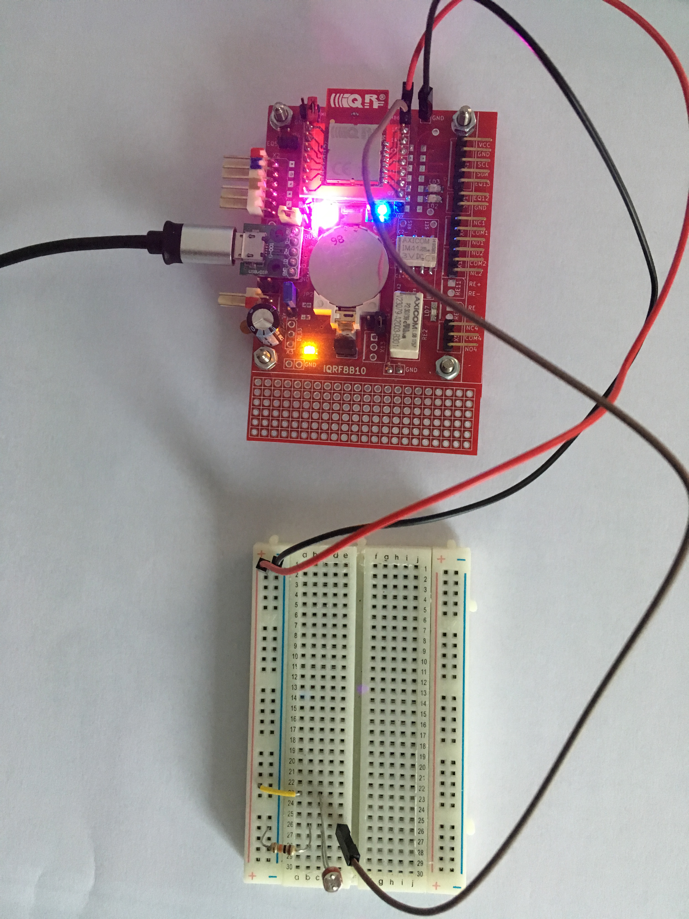
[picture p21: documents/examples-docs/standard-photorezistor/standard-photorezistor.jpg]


This example shows how to create "Standard Photorezistor Sensor" that will be immediately recognized and manageable from IOT world thanks to gateways and standardization.

## Prerequisities

1. **IQRFBB-10** bonded in working IQRF network. More in [Getting Started](../../README.md)
2. **IQRF Gateway Daemon** working. More in [IQRF Gateway Daemon](../../IqrfGatewayDaemon.md)
3. **Python 3.6 with WebSockets module**. More in [Python WebSockets example](../../IqrfGatewayDaemon.md#python-websocket-example)

## Hardware wiring



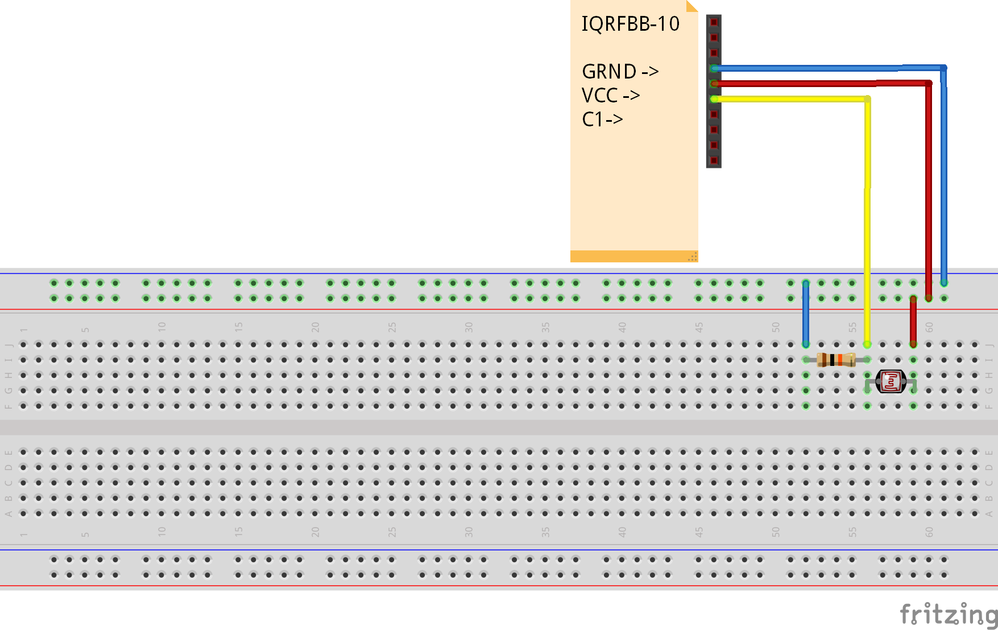
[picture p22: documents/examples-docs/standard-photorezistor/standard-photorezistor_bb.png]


Photorezistor is connected to GND, VCC and EQ14/C1/AN0. Since the board has LED5 on EQ14, this LED will be indicating a work of photorezistor.

## Software in TR module

The [standard-photorezistor.c](https://github.com/logimic/iqrfboard/blob/master/examples/standard-photorezistor.c) implements one binary input.
Please load this "Custom DPA Handler" to TR module on board. [Load Custom DPA Handler](../../SetupIqrfNetwork.md#load-custom-dpa-handler) manual.

## API JSON message

Since we implemented standard sensor we can use all standardized JSON messages for [Sensor ](https://docs.iqrfsdk.org/iqrf-gateway-daemon/api.html#sensor) via JSON API of gateways.

## Testing Python code

The [standard-photorezistor.py](https://github.com/logimic/iqrfboard/blob/master/examples/standard-photorezistor.py) does following:

- Gets number of implemented standard sensors in TR module.
- Reads sensor in loop of 20 measurements
- Displays measured value from JSON message

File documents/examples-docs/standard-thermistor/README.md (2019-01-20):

# Standard Thermistor Sensor

This example shows how to create "Standard Thermistor Sensor" that will be immediately recognized and manageable from IOT world thanks to gateways and standardization.

## Prerequisities

1. **IQRFBB-10** bonded in working IQRF network. More in [Getting Started](../../README.md)
2. **IQRF Gateway Daemon** working. More in [IQRF Gateway Daemon](../../IqrfGatewayDaemon.md)
3. **Python 3.6 with WebSockets module**. More in [Python WebSockets example](../../IqrfGatewayDaemon.md#python-websocket-example)

## Hardware wiring



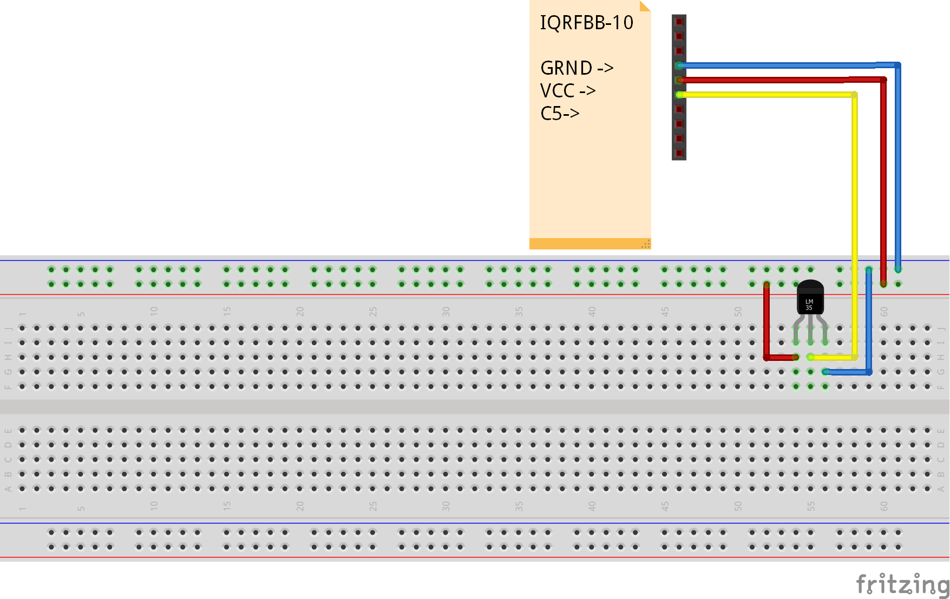
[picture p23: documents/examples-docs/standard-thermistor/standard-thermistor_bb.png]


Photorezistor is connected to GND, VCC and Q9(SS)/C5/AN4.

## Software in TR module

The [standard-thermistor.c](https://github.com/logimic/iqrfboard/blob/master/examples/standard-thermistor.c) implements one binary input.
Please load this "Custom DPA Handler" to TR module on board. [Load Custom DPA Handler](../../SetupIqrfNetwork.md#load-custom-dpa-handler) manual.

## API JSON message

Since we implemented standard sensor we can use all standardized JSON messages for [Sensor ](https://docs.iqrfsdk.org/iqrf-gateway-daemon/api.html#sensor) via JSON API of gateways.

## Testing Python code

The [standard-thermistor.py](https://github.com/logimic/iqrfboard/blob/master/examples/standard-thermistor.py) does following:

- Gets number of implemented standard sensors in TR module.
- Reads sensor in loop of 200 measurements
- Displays measured value from JSON message

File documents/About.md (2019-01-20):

# About



- IQRFBB-10 project is powered by [www.logimic.com](http://www.logimic.com)
- Orders & Project Presentation [logimic.com/iqrfboard](http://logimic.com/iqrfboard)

## Licensing

All content in the repository is licensed via the [MIT license](https://opensource.org/licenses/MIT)

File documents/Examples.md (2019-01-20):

# Examples with IQRFBB-10



# Standard Things

Standard things have pre-defined JSON API and all IQRF gateways know them.  If you implement your device in TR module as **Standard Light**, **Standard Binary Output**, **Standard Sensor** and more you have ensured compatibility of your device with IOT world.

## 1. Light


This example shows how to create "Standard light" from your board which means that entire world will know that your device is just a light and will be able to manage it (turn on/off, dim, get status and more). Your hardware design on the top of board is not limited.
[Enter example...](examples-docs/standard-light/README.md)

## 2. Binary Output


This example shows how to create one or more standard binary outputs on the board.
[Enter example..](examples-docs/standard-bin-output/README.md)

## 2. Bi-stable Relay


This example shows how to manage bi-stable relay on board via standard messages.
[Enter example..](examples-docs/standard-bistable-relay/README.md)

## 3. Photorezistor Sensor


This example shows how to create standard photorezistor sensor.
[Enter example..](examples-docs/standard-photorezistor/README.md)

## 4. Thermistor Sensor


This example shows how to create standard thermistor sensor.
[Enter example..](examples-docs/standard-thermistor/README.md)

# Pure DPA messages

## 1. Digital Output


This example shows how to set HI/LO digital output. The DO has connected external LED.
[Enter example..](examples-docs/digital-output/README.md)

## 2. Digital Input


This example explains how to detect digital input on board PIN.
[Enter example..](examples-docs/digital-input/README.md)

## 3. Hall Magnetic Sensor


This example shows how to connect Hall Magentic Sensor with the board and detect event.
[Enter example..](examples-docs/dpa-hall/README.md)

## 4. Motion detection (ePir)


This example shows how to connect motion sensor ePir to the board and detect event.
[Enter example..](examples-docs/dpa-epir/README.md).

## 5. Bi-stable relay on board


This example shows how to switch bi-stable relay on board.
[Enter example..](examples-docs/dpa-bistable-relay/README.md)

## 6. HTU21D - Temp & Humidity


This example shows how to connect HTU21D Temperature and Humidity sensor to board.
[Enter example..](examples-docs/dpa-htu21d/README.md)

# IQRF Embedded things

## 1. Embedded LED on board


First hello world example which turns on/off RED and GREEN diods on the IQRFBB-10 board.
[Enter example...](examples-docs/embedded-led/README.md)

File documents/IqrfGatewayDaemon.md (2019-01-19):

# IQRF Gateway Daemon
IQRF network is hidden behind coordinator connected to your computer via USB, SPI, UART or other types of interface. Communication between your program and coordinator is ensured via **IQRF Gateway Daemon** software module.
This is Open Source gateway piece of software for communicating (sending and receiving JSON API messages) with IQRF network. This is included in many IQRF gateways and you can also download it and build for your platform.

## Run Daemon
You can run Daemon on any computer with Lin or Win platform where you have connected concentrator via USB or otherwise. The most simply way is to connect concentrator via USB to your local PC and run Daemon here.

### Windows Developers
 We prepared [IQRF Gateway Daemon Release for Win](https://github.com/logimic/iqrfboard/releases), please follow instruction how to install and start.

### Linux Developers
Please install from packages as described in [IQRF Gateway Daemon Documentation](https://docs.iqrfsdk.org/iqrf-gateway-daemon/). After restart of your Linux machine Dameon will really run as "Daemon".

## WebSockets JSON API
WebSockets port is opened during start o Daemon. The number of port is defined in **IqrfDaemon\runcfg\iqrfgd2-WinCdc\configuration\iqrf__WebsocketMessaging.json**.  You can change it, but please do not forget to restart Daemon then.

### Html WebSocket example
* Open html page **https://github.com/logimic/iqrfboard/blob/master/tools/index-1338.html**
* Enter message:

```json
{
  "mType": "iqrfEmbedLedg_Set",
  "data": {
    "msgId": "testEmbedLedr",
    "req": {
      "nAdr": 0,
      "param": {
        "onOff": true
      }
    },
    "returnVerbose": true
  }
}
```

* Press **Send** in html page and see that this turned on the LED diod on concentrator module.
* Similar way you can turn LED off:

```json
{
  "mType": "iqrfEmbedLedg_Set",
  "data": {
    "msgId": "testEmbedLedr",
    "req": {
      "nAdr": 0,
      "param": {
        "onOff": false
      }
    },
    "returnVerbose": true
  }
}
```

* Similarly for other nodes by changing **nAdr** parameter indicating the node address.
* Full API description can be found here: https://docs.iqrfsdk.org/iqrf-gateway-daemon/api.html

### Python WebSocket example
* Install Python 3.6
* Install ```pip install websockets```
* Write simple program **[GreenLedOn.py](tools/GreenLedOn.py)**
```py
# WS client example
import asyncio
import websockets
import json

x = {
  "mType": "iqrfEmbedLedg_Set",
  "data": {
    "msgId": "testEmbedLedr",
    "req": {
      "nAdr": 0,
      "param": {
        "onOff": True
      }
    },
    "returnVerbose": False
  }
}

async def hello():
    async with websockets.connect(
            'ws://localhost:1338') as websocket:

        await websocket.send(json.dumps(x))
        print(f"Sent > {x}")

        greeting = await websocket.recv()
        print(f"Received < {greeting}")

asyncio.get_event_loop().run_until_complete(hello())
```
* Run it ``$ py ./GreenLedOn.py`` and the green LED on coordinator turns on.
* Changing **nAdr** will address command to other node, the **"onOff": False** will turn LED off.

## Links
[Links](Links.md)

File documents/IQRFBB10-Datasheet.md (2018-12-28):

# IQRFBB10 Data Sheet

**Revision:** 1.0, Nov-2018

## 1. Description

IQRFBB10 is development board for prototyping of end devices (nodes) of IQRF network. Board includes socket for IQRF transciever module plugin and enables connection of any sensors, acttuators via DI, DIO, or I2C interfaces. Software operation of sensors and data transfer is performed in MCU of IQRF radio transciever module.

## 2. Specification

| | |
| --- | --- |
| **Power supply** | |
| - Accumulator | LIP552240, 400 mAh, nominal voltage 3.7 V |
| - Via micro USB connector (with charging) | 4.4 V to 6.0 V DC |
| - External power supply | 5-12 V |
| - External accumulator | pres X6, nominal voltage 3.7 V |
| **Supply current** | |
| - ??? | |
| **Temperature operating** | |
| - Accumulator not charged | -20°C to +60°C |
| - Accumulator charged | 0 °C to +45 °C |
| **Storage Temperature** | -20°C to +20°C (1 year), +10°C to +25°C recommended |
| **Supported TR modules** | TR-76DA and similar |
| **Dimensions** | 60 mm x 85 mm x 23 mm |
| **Weight** | 30g |
| | |

## 3. Simple scheme



_Fig1. Simple schema of IQRF BB-10 board_

## 4. Features

| **Name** | **Type** | **Description** |
|:--- |:--- | --- |
| U4 | | IQRF TR module socket |
| Bat1 | LIR2032 | Chargeable battery |
| USB | uUSD_to_DIP | PCB adapter |
| Bist-rel | ME-6C-L1-03-1a1b | Bi-stable relay 3V |
| RE-STD | IM-HICPD | Standard releay |
| | | |

## 5. PINs specification

| **Pin** | **Name** | **Description** |
|:--- |:--- | --- |
| VCC | | Power supply voltage |
| GND | | Ground |
| SCL | | I2C clock |
| SDA | | I2C data |
| EQ13 | TA | General input only pin |
| EQ12 | SW1 | |
| GND | SW1 | Ground |
| NC1 | | Bi-stable relay TH |
| COM1 | | Bi-stable relay TH |
| NO1 | | Bi-stable relay TH |
| NO2 | | |
| COM2 | | Bi-stable relay SMD |
| NC2 | | Bi-stable relay SMD |
| RE+ | | Output for power supply of Bi-stable relay (+/- 3V) |
| RE- | | Output for power supply of Bi-stable relay (+/- 3V) |
| RE | | Output for power supply of Bi-stable relay |
| RE+++ | | Output for power supply of Bi-stable relay |
| NC4 | | Standard relay |
| COM4 | | Standard relay |
| NO4 | | Standard relay |
| MB1 | C1 | |
| MB2 | C2 | |
| MB3 | VO | |
| MB4 | | |
| MB5 | VCC | |
| MB6 | | |
| MB7 | | |
| MB8 | | |
| X13 | | Contact of Standard relay (paket_2) |
| PGM 1 | VCC | |
| PGM 2 | GND | |
| PGM 3 | SCK | |
| PGM 4 | SDI | |
| PGM 5 | SDO | |
| PGM 6 | SS | |

### IQRF module PIN mapping

| **PIN** | **IQRF PIN** | |
| --- | --- | --- |
| XQ2 | GND | |
| XQ3 | VCC | |
| XQ4 | Q4 | |
| XQ5 | Q5 | |
| XQ6 | Q6 | |
| XQ7 | Q7 | |
| XQ8 | Q8 | |
| XQ9 | Q9 | |
| XQ10 | Q10 | |
| XQ11 | Q11 | |
| XQ12 | Q12 | |
| XQ13 | Q13 | |
| XQ14 | Q14 | |
| XQ15 | Q15 | |
| | | |

## 6. Jumpers

| **Jumper** | **Description** | **Description** |
|:--- |:--- | --- |
| JP1 | VCC_SW | Enable connection of local source 3V. Note: connect local source after un-plug of programmer! |
| JP2 | | Power cupply choise <br> 1-2: LiPol/USB adapter 5V (board works withouth battery) <br>2-3: external power supply 5-16V z X1 |
| JP3 | | |
| JP4 | VCC_SW | Connects indication of powwer supplyLD4-Y (3V) |
| JP5 | | Host_mode at Android devices if possible |
| JP6 | VCC_SW | Connects battery to power supply |
| X6 | | Connects external Lipol battery |
| | | |

## 7. Diods

| **Diod** | **Name** | **Description** |
|:--- |:--- | --- |
| LD1 | LED-P | |
| LD2 | LED-G | |
| LD3 | LED-R | |
| LD4 | LED-Y | Indication of power supply (3V) |
| LD5 | LED-B | |
| LD6 | LED-W | |
| LD7 | LED-O | |
| | | |

## 8. Operation conditions

TODO

## 9. Programmer connection



_Fig2. programmer connection with IQRF BB-10 board_

* Connect with **CK-USB-04A** programmer.
* No TR module in programmer.

## 10. Detail scheme



_Fig3. Detail scheme of IQRF BB-10 board_

## 11. Contacts

[www.logimic.com](http://www.logimic.com)

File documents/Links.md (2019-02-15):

# Links


## IQRFBB-10 Links

* [IQRFBB-10 Presentation & Buy](http://logimic.com/iqrfboard)
* [IQRFBB-10 GitHub pages](https://github.com/logimic/iqrfboard)
* [IQRFBB-10 Data Sheet](datasheet/IQRFBB10-Datasheet.md)
    - [IQRFBB-10 Data Sheet (pdf)](files/datasheet/IQRFBB10-Datasheet.pdf)
    - [IQRFBB-10 Board Schema (pdf)](files/datasheet/IQRFBB10-Connectors.pdf)
    - [IQRFBB-10 Hardware Drawing (pdf)](files/datasheet/IQRFBB10_doc_sch.pdf)
* [TR-76D Transciever](https://iqrf.org/products/transceivers/tr-76d)
    - [TR-76D Datasheet](http://iqrf.org/weben/downloads.php?id=441)

## IQRF Gateway daemon

* [IQRF Gateway Daemon Sources](https://gitlab.iqrfsdk.org/gateway/iqrf-daemon)
* [IQRF Gateway Daemon Release for Win](https://github.com/logimic/iqrfboard/releases)
* [IQRF Gateway Daemon Documentation](https://docs.iqrfsdk.org/iqrf-gateway-daemon/)

## IQRF General Links

* [IQMESH Network Deployment](https://www.iqrf.org/support/download&kat=54&ids=564)
* [DS-START-04 development kit page](https://iqrf.org/products/ds-start-04)
    * [IQRF Quick Start Guide](http://www.iqrf.org/weben/downloads.php?id=235)
    * [IQRF Startup Package](http://www.iqrf.org/weben/downloads.php?id=82)
    * [CK-USB-04A (programmer)](https://iqrf.org/products/development-tools/development-kits/ck-usb-04a)
* [DPA Framework on-line](https://www.iqrf.org/DpaTechGuide/)
* [IQRF Standards](https://www.iqrfalliance.org/techDocs/)
* [IQRF Repository API](https://repository.iqrfalliance.org/doc/api/)

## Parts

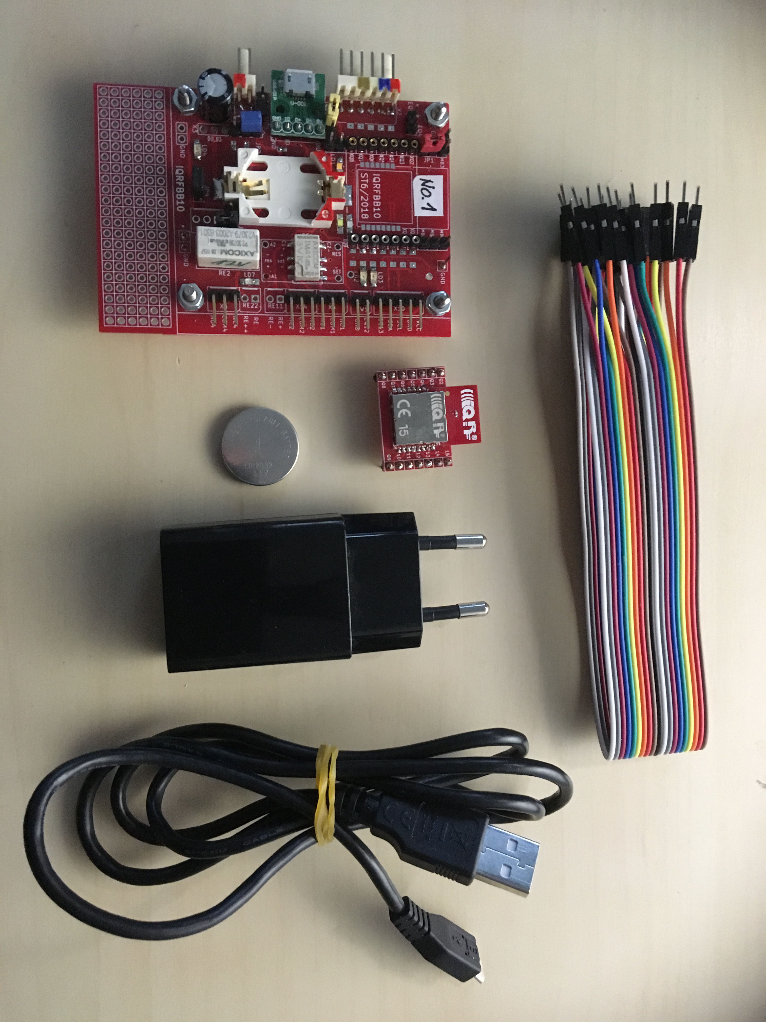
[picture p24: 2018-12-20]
documents/files/images/allParts.jpg

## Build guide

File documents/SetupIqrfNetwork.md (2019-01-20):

# Setup IQRF Network



You can get many pieces of information about IQRF at [iqrf.org](http://iqrf.org) page. Simply said IQRF network is mesh kind of network working very well indoor and outdoor (up to 500m). It has one device as **concentrator** connected to gateway or your PC and the rest of devices are **wireless nodes**.

The best start with IQRF is with their **DS-START-04** development kit. It helps you to create your first IQRF network for testing purposes. In this tutorial we will show you how to create IQRF network with this kit.

## Install IDE

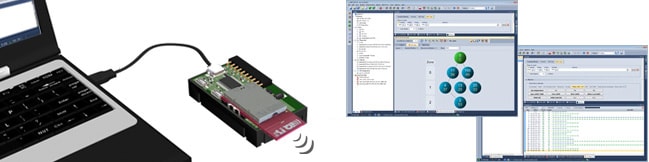
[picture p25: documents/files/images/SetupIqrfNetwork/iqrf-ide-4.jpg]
aaa


IDE is a basic programming tool for IQRF devices. Download and install [https://www.iqrf.org/technology/iqrf-ide/iqrf-ide-gui](https://www.iqrf.org/technology/iqrf-ide/iqrf-ide-gui)

## Install IQRF Startup Package

Download [IQRF Startup package](https://www.iqrf.org/support/download&kat=34&ids=82) and unpack anywhere to your hard drive.

## First Start

* Start your IDE, navigate to your installed **IQRF Startup package** e.g. _d:\IQRF_OS403_7xD\Examples\DPA\StartUp_ and open **HWP-demo.iqrfprj**

* Insert any IQRF module to programmer [CK-USB-04A](https://iqrf.org/products/development-tools/development-kits/ck-usb-04a) and connect to PC via USB.

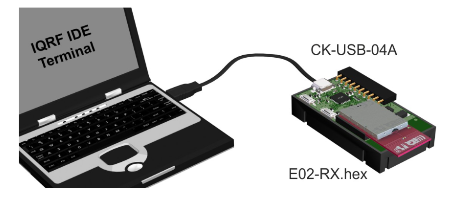
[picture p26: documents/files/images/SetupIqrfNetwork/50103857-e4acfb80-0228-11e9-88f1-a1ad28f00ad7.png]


* In IDE you will probably see **USB device not connected** in bottom panel.



* Go to menu **Tools/USB Classes/Swith to Custom Device mode** and select listed COM (USB) port. If you do not see any port please follow troubleshooting on IQRF support. You need driver update. Successful selection will show dialogue like this.

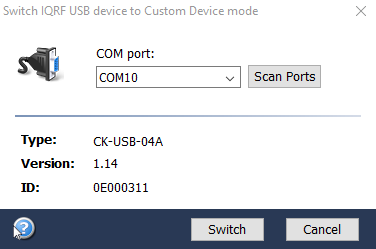
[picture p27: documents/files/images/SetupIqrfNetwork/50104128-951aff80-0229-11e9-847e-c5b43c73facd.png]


* Click **Switch** and the bottom panel will show **Module ready - communication mode**



* It might show dialogue about firmware update, then click **Yes**.

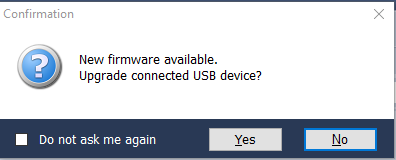
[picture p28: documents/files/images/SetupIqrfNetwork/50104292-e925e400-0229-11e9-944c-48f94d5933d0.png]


* Click **Upload** button, wait for firmware update, then press **Close**.

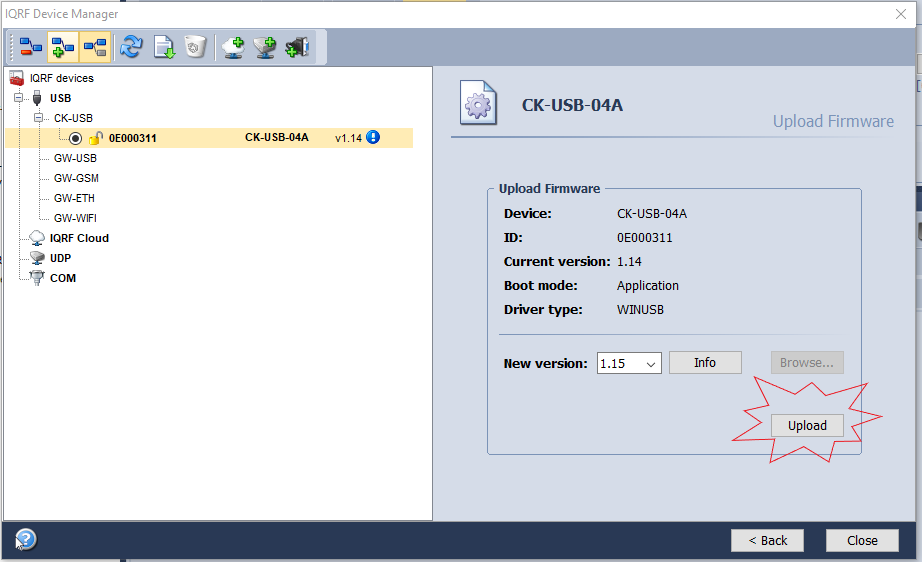
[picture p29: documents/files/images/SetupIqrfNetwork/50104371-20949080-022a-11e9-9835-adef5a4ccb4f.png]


## Configure Coordinator

A Concentrator is the node connected with PC or Gateway gathering data from all nodes.
**! When you insert or remove TR from holder, always press SW2 button (nearer to SIM slot). It breaks power.**

* In left panel check **HWP-Coordinator-...iqrf** file

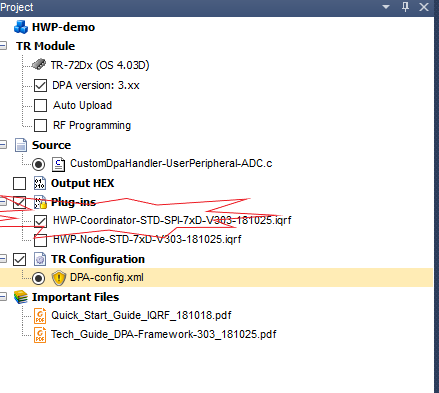
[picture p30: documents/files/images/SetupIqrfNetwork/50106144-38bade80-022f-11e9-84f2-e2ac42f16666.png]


* Double click on **DPA-config.xml** in left panel. Set items in dialogue as picture shows and click **Upload** button.

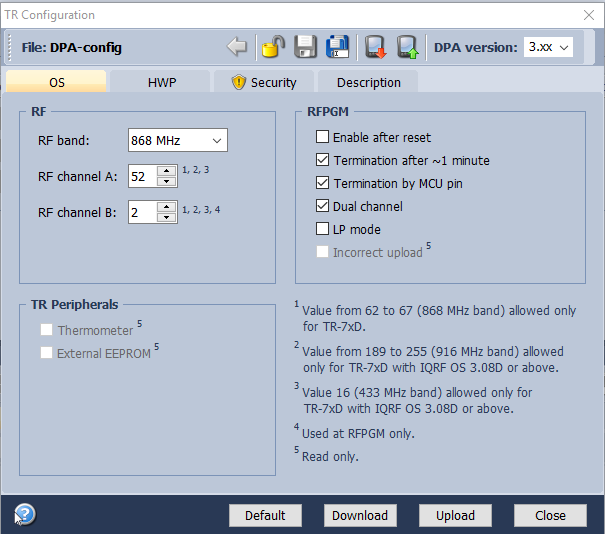
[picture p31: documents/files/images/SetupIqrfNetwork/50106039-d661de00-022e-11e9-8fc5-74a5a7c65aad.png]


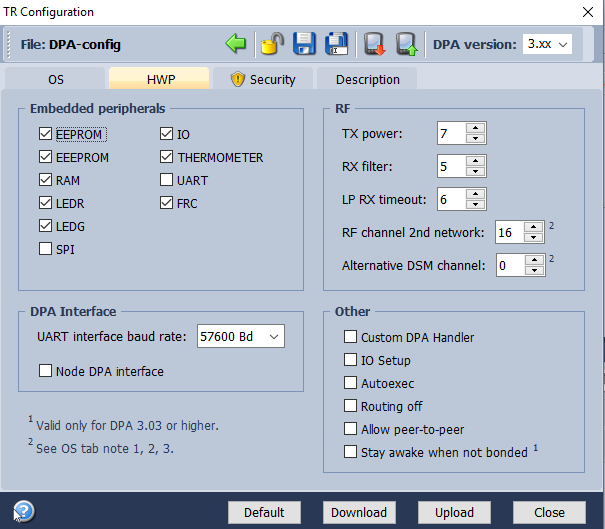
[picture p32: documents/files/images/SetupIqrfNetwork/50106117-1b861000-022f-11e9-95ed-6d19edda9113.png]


* In menu select **Programming/Upload/Upload Selected Items**. If the system complains that uploading version is not for the connected TR module, please upgrade OS in module. See **Upgrade OS in TR module** section.

## Configure Nodes

A Node is a module communication within mesh with Concentrator.
**! When you insert or remove TR from holder, always press SW2 button (nearer to SIM slot). It breaks power.**

* Insert TR module to be node into programmer

* In left panel of IDE check **HWP-Node-STD-...**

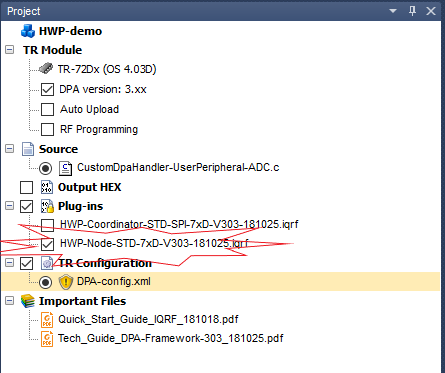
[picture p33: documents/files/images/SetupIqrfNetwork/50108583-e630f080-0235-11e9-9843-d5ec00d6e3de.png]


* Keep the **DPA-config.xml** settings as previously at concentrator.

* Upload all your nodes. If the system complains that uploading version is not for the connected TR module, please upgrade OS in module. See **Upgrade OS in TR module** section.

## Upgrade OS in modules

* In menu select **Tools/Change IQRF OS Wizard** and follow wizard.

* Use **SPI** as upload method.

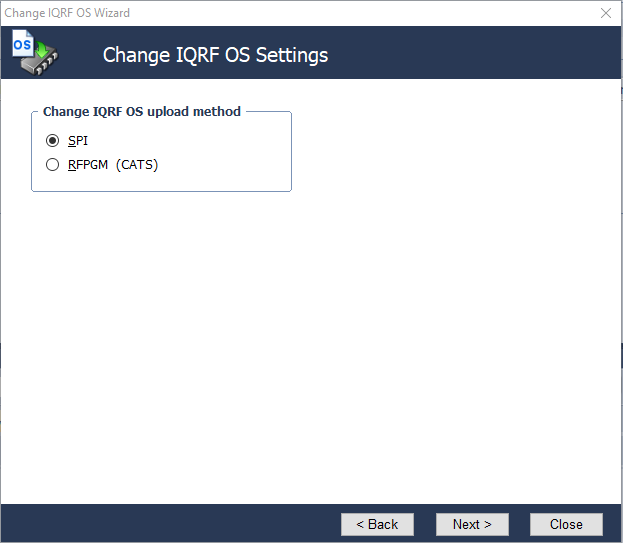
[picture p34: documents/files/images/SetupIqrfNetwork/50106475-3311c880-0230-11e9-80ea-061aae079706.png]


* Then select version to be uploaded

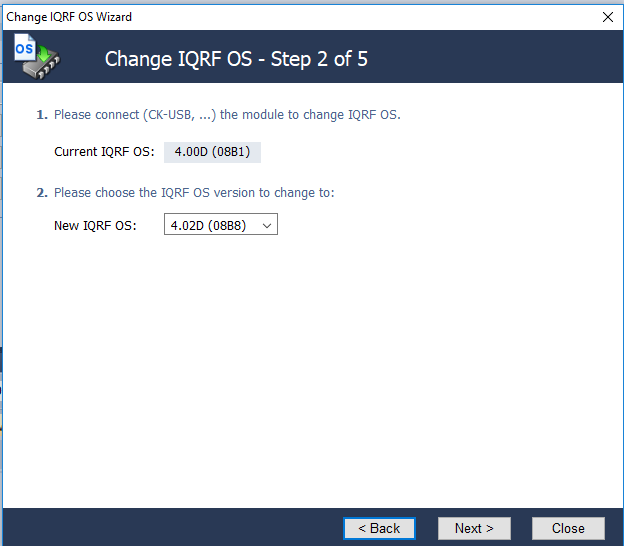
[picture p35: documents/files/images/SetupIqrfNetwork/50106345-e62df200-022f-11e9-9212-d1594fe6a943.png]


* **!If your modules are older you might need to repeat the upgrade OS more times**

## Run Network

* Insert coordinator configured TR module to programmer CK-USB-04A and nodes to other DK-EVAL-04A modules.

* In IDE in menu start **Tools/IQMESH Network Manager** and fill out the dialogue as shown (TX power, Auto address, ...).



* Then pres **Clear All Bonds** for remove any previous bonded modules. Red diods of modules are blinking.

* Then pres **Bond Node** and during bonding period press and hold SW1 button at one node until green red turns on. Repeat for each node.



* Now you should see two spots indicating successful bonding. Now click **Discovery** and spots are in blue.



* Switch in IDE to **Map View** and you should see node structure

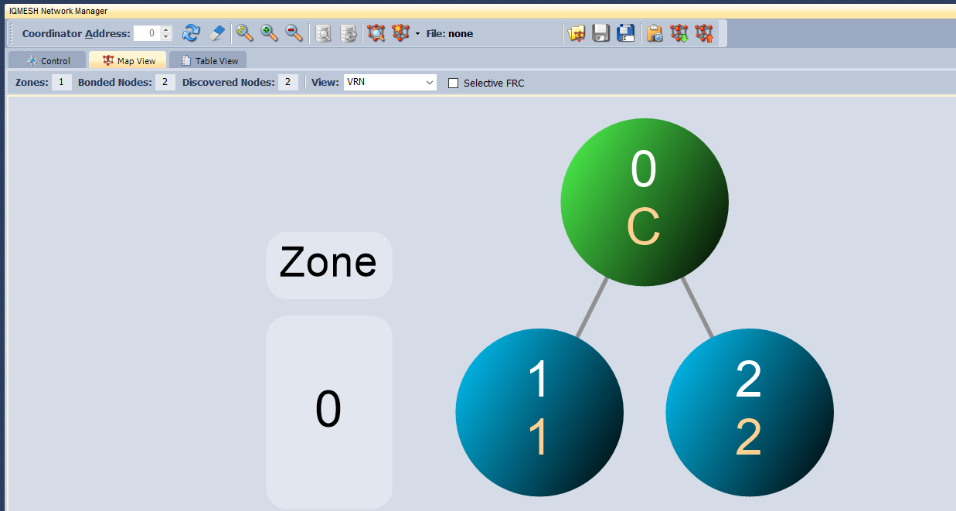
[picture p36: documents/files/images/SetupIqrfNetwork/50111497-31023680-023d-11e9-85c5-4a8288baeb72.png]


* Click right mouse button on node 1 and select **LED Red On**

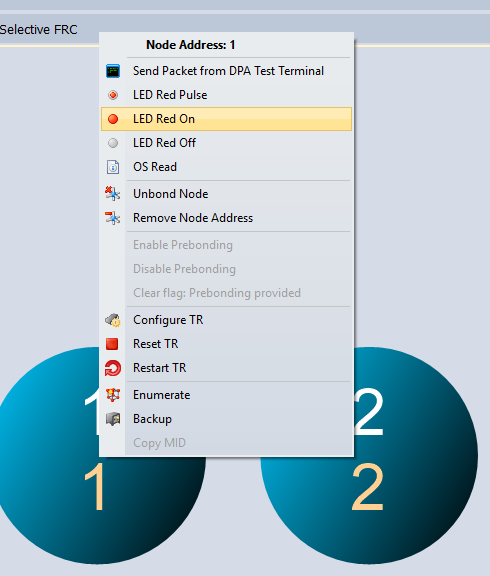
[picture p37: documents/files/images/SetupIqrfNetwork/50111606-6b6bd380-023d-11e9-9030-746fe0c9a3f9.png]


* Now you can see that the **RED LED** of node 1 is on. In similar way you can turn-off or play with LEDs.

## Send DPA messages

Direct Peripheral Access (DPA) protocol is a simple byte-oriented protocol used to control nodes and network. Detail description of [DPA Framework](https://www.iqrf.org/DpaTechGuide/)

* DPA can be sent via IDE. Open **Terminal** and click **Set LEDR on** which prefills data into **Data to send** fields. Change only **NADR=0001** which indicates node 1 and click **Send**.

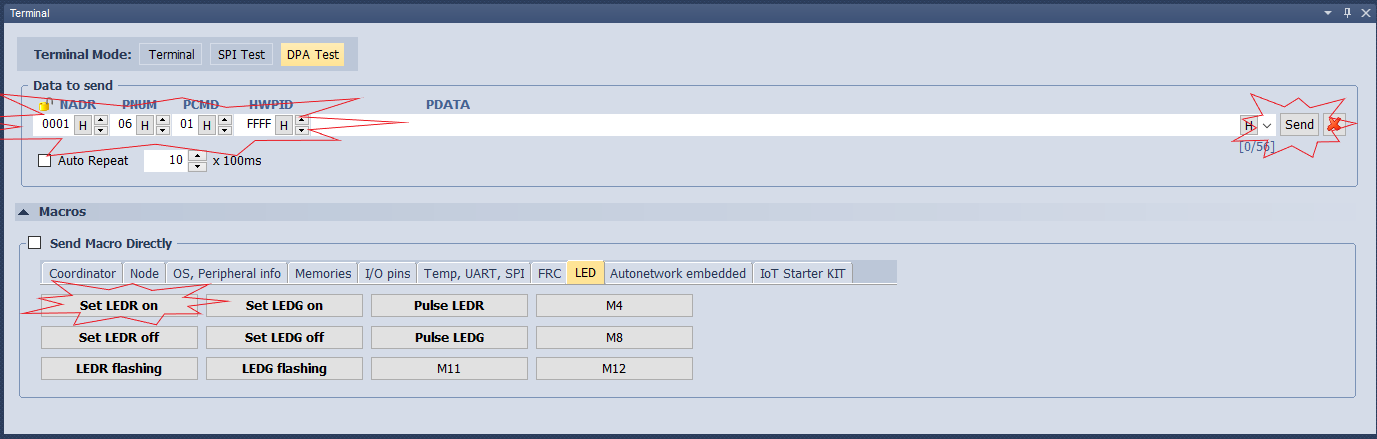
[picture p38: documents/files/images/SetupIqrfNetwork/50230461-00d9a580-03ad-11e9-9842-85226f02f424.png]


* This DPA command turned on RED diod on node 1.
* You can define any other DPA messages.

## Load Custom DPA Handler

**Custom DPA Handler** is software routine which is executed within transceiver MCU and where you can put your customer code to modify.

In **IDE Project** window you can see actually loaded **CustomDpaHandler** under **Source** item. Under **Output HEX** is its compiled code.
You can click right mouse button above source of **CustomDpaHandler-..** file and choose **Build** from menu for rebuilding of handler.

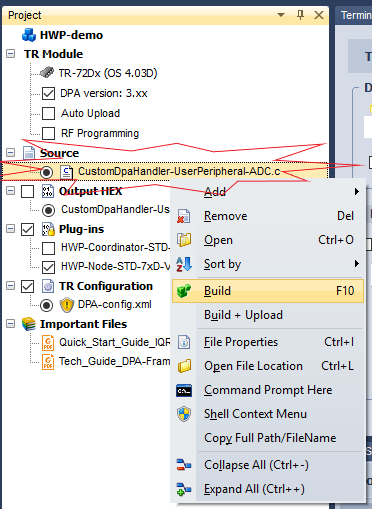
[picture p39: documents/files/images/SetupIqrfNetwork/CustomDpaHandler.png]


You can load any other Custom DPA Handler from prepared set in IQRF SDK here: **./IQRF_OS403_7xD/Examples/DPA/CustomDpaHandlerExamples** or you can modify any or write your own. **Note:** When you create your own handler, put it into **CustomDpaHandlerExamples** folder to be available others IQRF header files.

**Adding of your Custom DPA Handler:**

1. Right-click on any existing Custom DPA Handler under **Source**.
2. From context menu select **Add/Add Existing Item** and select your **CustomDpaHandler.c** file.
3. Make sure your handler is selected and via right-click select **Build** for its rebuild.
4. You will see its compiled **.hex** state under **Output Hex** item.
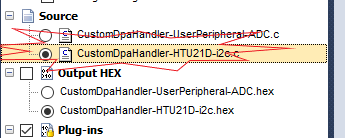
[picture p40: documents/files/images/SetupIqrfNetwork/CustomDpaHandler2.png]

5. Right-click on the **.hex** file and select **Upload**. Now the handler will be uploaded to TR module.
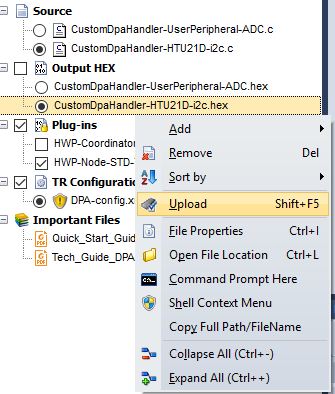
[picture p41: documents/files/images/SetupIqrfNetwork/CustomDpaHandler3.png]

6. Then double-click on **DPA-config.xml** and in dialogue tick **Custom DPA Handler** and then **Upload**.
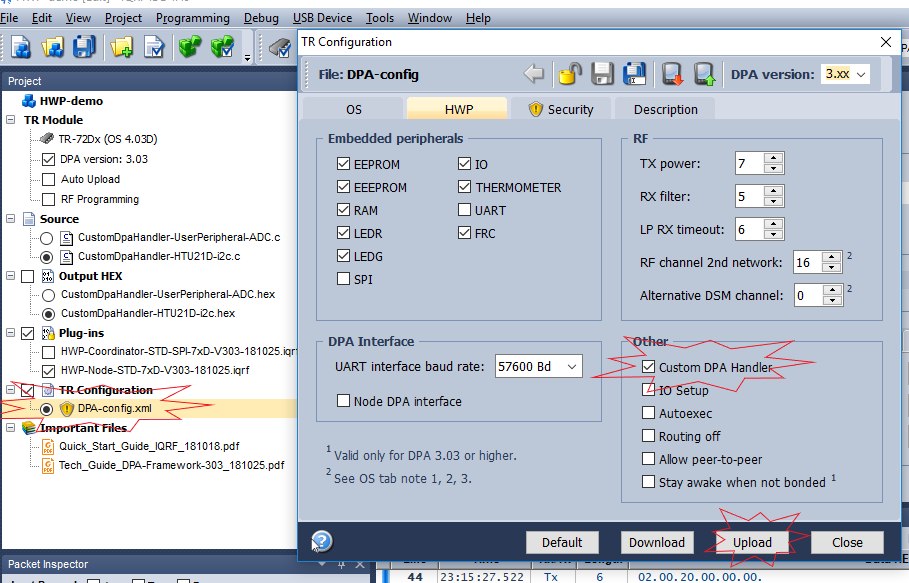
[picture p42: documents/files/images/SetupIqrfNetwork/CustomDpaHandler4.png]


## Your own IQRF devices

Now it's time to build your own IQRF device. The best start is with IQRFBB-10 development board from [Logimic](http://www.logimic.com) because it has many examples and you can reuse board layout and design for your later product development. Let's go with [IQRFBB-10 board](README.md)

## Links
[Links](Links.md)

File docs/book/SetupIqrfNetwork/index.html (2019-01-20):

Toggle navigation IQRFBB-10

- GettingStarted
  - Getting Started with IQRFBB-10
  - Examples
  - Data Sheet
  - Data Sheet (pdf)
  - Buy (http://logimic.com/iqrfboard/index.html#pricing-tables2-16)
- IQRF Network
  - Setup IQRF Network
  - IQRF Gateway Daemon
- Links
- About
- GitHub Repo (https://github.com/logimic/iqrfboard)
- Search
- Previous
- Next
- Setup IQRF Network
- Install IDE
- Install IQRF Startup Package
- First Start
- Configure Coordinator
- Configure Nodes
- Upgrade OS in modules
- Run Network
- Send DPA messages
- Load Custom DPA Handler
- Your own IQRF devices
- Links

# Setup IQRF Network



You can get many pieces of information about IQRF at iqrf.org page. Simply said IQRF network is mesh kind of network working very well indoor and outdoor (up to 500m). It has one device as concentrator connected to gateway or your PC and the rest of devices are wireless nodes.

The best start with IQRF is with their DS-START-04 development kit. It helps you to create your first IQRF network for testing purposes. In this tutorial we will show you how to create IQRF network with this kit.

## Install IDE

aaa

IDE is a basic programming tool for IQRF devices. Download and install https://www.iqrf.org/technology/iqrf-ide/iqrf-ide-gui

## Install IQRF Startup Package

Download IQRF Startup package (https://www.iqrf.org/support/download&kat=34&ids=82) and unpack anywhere to your hard drive.

## First Start

- Start your IDE, navigate to your installed IQRF Startup package e.g. d:\IQRF_OS403_7xD\Examples\DPA\StartUp and open HWP-demo.iqrfprj
- Insert any IQRF module to programmer CK-USB-04A (https://iqrf.org/products/development-tools/development-kits/ck-usb-04a) and connect to PC via USB.



- In IDE you will probably see USB device not connected in bottom panel.



- Go to menu Tools/USB Classes/Swith to Custom Device mode and select listed COM (USB) port. If you do not see any port please follow troubleshooting on IQRF support. You need driver update. Successful selection will show dialogue like this.



- Click Switch and the bottom panel will show Module ready - communication mode



- It might show dialogue about firmware update, then click Yes.



- Click Upload button, wait for firmware update, then press Close.



## Configure Coordinator

A Concentrator is the node connected with PC or Gateway gathering data from all nodes. ! When you insert or remove TR from holder, always press SW2 button (nearer to SIM slot). It breaks power.

- In left panel check HWP-Coordinator-...iqrf file



- Double click on DPA-config.xml in left panel. Set items in dialogue as picture shows and click Upload button.





- In menu select Programming/Upload/Upload Selected Items. If the system complains that uploading version is not for the connected TR module, please upgrade OS in module. See Upgrade OS in TR module section.

## Configure Nodes

A Node is a module communication within mesh with Concentrator. ! When you insert or remove TR from holder, always press SW2 button (nearer to SIM slot). It breaks power.

- Insert TR module to be node into programmer
- In left panel of IDE check HWP-Node-STD-...



- Keep the DPA-config.xml settings as previously at concentrator.
- Upload all your nodes. If the system complains that uploading version is not for the connected TR module, please upgrade OS in module. See Upgrade OS in TR module section.

## Upgrade OS in modules

- In menu select Tools/Change IQRF OS Wizard and follow wizard.
- Use SPI as upload method.



- Then select version to be uploaded



- !If your modules are older you might need to repeat the upgrade OS more times

## Run Network

- Insert coordinator configured TR module to programmer CK-USB-04A and nodes to other DK-EVAL-04A modules.
- In IDE in menu start Tools/IQMESH Network Manager and fill out the dialogue as shown (TX power, Auto address, ...).



- Then pres Clear All Bonds for remove any previous bonded modules. Red diods of modules are blinking.
- Then pres Bond Node and during bonding period press and hold SW1 button at one node until green red turns on. Repeat for each node.



- Now you should see two spots indicating successful bonding. Now click Discovery and spots are in blue.



- Switch in IDE to Map View and you should see node structure



- Click right mouse button on node 1 and select LED Red On



- Now you can see that the RED LED of node 1 is on. In similar way you can turn-off or play with LEDs.

## Send DPA messages

Direct Peripheral Access (DPA) protocol is a simple byte-oriented protocol used to control nodes and network. Detail description of DPA Framework (https://www.iqrf.org/DpaTechGuide/)

- DPA can be sent via IDE. Open Terminal and click Set LEDR on which prefills data into Data to send fields. Change only NADR=0001 which indicates node 1 and click Send.



- This DPA command turned on RED diod on node 1.
- You can define any other DPA messages.

## Load Custom DPA Handler

Custom DPA Handler is software routine which is executed within transceiver MCU and where you can put your customer code to modify.

In IDE Project window you can see actually loaded CustomDpaHandler under Source item. Under Output HEX is its compiled code. You can click right mouse button above source of CustomDpaHandler-.. file and choose Build from menu for rebuilding of handler.



You can load any other Custom DPA Handler from prepared set in IQRF SDK here: ./IQRF_OS403_7xD/Examples/DPA/CustomDpaHandlerExamples or you can modify any or write your own. Note: When you create your own handler, put it into CustomDpaHandlerExamples folder to be available others IQRF header files.

Adding of your Custom DPA Handler:

1. Right-click on any existing Custom DPA Handler under Source.
2. From context menu select Add/Add Existing Item and select your CustomDpaHandler.c file.
3. Make sure your handler is selected and via right-click select Build for its rebuild.
4. You will see its compiled .hex state under Output Hex item. 
5. Right-click on the .hex file and select Upload. Now the handler will be uploaded to TR module. 
6. Then double-click on DPA-config.xml and in dialogue tick Custom DPA Handler and then Upload. 

## Your own IQRF devices

Now it's time to build your own IQRF device. The best start is with IQRFBB-10 development board from Logimic (http://www.logimic.com) because it has many examples and you can reuse board layout and design for your later product development. Let's go with IQRFBB-10 board

## Links

Links

Copyright 2018, All rights reserved, Logimic, s.r.o.

Documentation built with MkDocs (https://www.mkdocs.org/).

×Close

#### Search

From here you can search these documents. Enter your search terms below.

×Close

#### Keyboard Shortcuts

Keys | Action
? | Open this help
n | Next page
p | Previous page
s | Search

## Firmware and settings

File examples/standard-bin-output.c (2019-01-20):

/**
* Copyright Logimic,s.r.o., www.logimic.com
*
* Licensed under the Apache License, Version 2.0 (the "License");
* you may not use this file except in compliance with the License.
* You may obtain a copy of the License at
*
*     http://www.apache.org/licenses/LICENSE-2.0
*
* Unless required by applicable law or agreed to in writing, software
* distributed under the License is distributed on an "AS IS" BASIS,
* WITHOUT WARRANTIES OR CONDITIONS OF ANY KIND, either express or implied.
* See the License for the specific language governing permissions and
* limitations under the License.
*/

// Online DPA documentation http://www.iqrf.org/DpaTechGuide/

// This example implements 4 binary outputs according to the IQRF Binary Outputs standard
// Outputs for IQRFBB-10 Development Board
// Index 0: Red LED @ LED3
// Index 1: Green LED @ LED2
// Index 2: Relay #1 @ Bi-stable relay C1
// Index 3: Relay #2 @ Bi-stable relay C2
// Index 4: Relay #2 @ EQ6/SCL out

// Default IQRF include (modify the path according to your setup)
#include "include/IQRF_OS/IQRF.h"
// Default DPA header (modify the path according to your setup)
#include "include/DPA/DPA.h"
// Default Custom DPA Handler header (modify the path according to your setup)
#include "include/DPA/DPAcustomHandler.h"
// IQRF standards header (modify the path according to your setup)
#include "include/DPA/IQRFstandard.h"
#include "include/DPA/IQRF_HWPID.h"

#if DPA_VERSION_MASTER	< 0x0301
#error DPA version 3.01++ is required
#endif

//############################################################################################

// Number of implemented binary outputs
#define	OUTPUTS_COUNT 5

// Sets and Gets state of the indexed binary output
void SetOutput( uns8 state, uns8 index );
bit GetOutput( uns8 index );

// DDC-RE-01 relay pins
//  A.0 = C1 = Relay#1
#define	RELAY1_LAT	LATA.0 
#define	RELAY1_TRIS	TRISA.0
//  C.2 = C2 = Relay#2
#define	RELAY2_LAT	LATC.2 
#define	RELAY2_TRIS	TRISC.2
//  C.3 = C6 = Simple DO
#define	RELAY3_LAT	LATC.3 
#define	RELAY3_TRIS	TRISC.3

// Must be the 1st defined function in the source code in order to be placed at the correct FLASH location!
//############################################################################################
bit CustomDpaHandler()
//############################################################################################
{
  // This forces CC5X to wisely use MOVLB instructions (doc says:  The 'default' bank is used by the compiler for loops and labels when the algorithm gives up finding the optimal choice)
#pragma updateBank default = UserBank_01

  // Timers for outputs. The space must be long enough to fit them all. 2 bytes per one binary output.
  static uns16	Timers[OUTPUTS_COUNT];

  // Handler presence mark
  clrwdt();

  // Detect DPA event to handle
  switch ( GetDpaEvent() )
  {
    // -------------------------------------------------
    case DpaEvent_Interrupt:
      // Do an extra quick background interrupt work
      // ! The time spent handling this event is critical.If there is no interrupt to handle return immediately otherwise keep the code as fast as possible.
      // ! Make sure the event is the 1st case in the main switch statement at the handler routine.This ensures that the event is handled as the 1st one.
      // ! It is desirable that this event is handled with immediate return even if it is not used by the custom handler because the Interrupt event is raised on every MCU interrupt and the �empty� return handler ensures the shortest possible interrupt routine response time.
      // ! Only global variables or local ones marked by static keyword can be used to allow reentrancy.
      // ! Make sure race condition does not occur when accessing those variables at other places.
      // ! Make sure( inspect.lst file generated by C compiler ) compiler does not create any hidden temporary local variable( occurs when using division, multiplication or bit shifts ) at the event handler code.The name of such variable is usually Cnumbercnt.
      // ! Do not call any OS functions except setINDFx().
      // ! Do not use any OS variables especially for writing access.
      // ! All above rules apply also to any other function being called from the event handler code, although calling any function from Interrupt event is not recommended because of additional MCU stack usage.

      //  If TMR6 interrupt occurred, every 10 ms
      if ( TMR6IF )
      {
        // Unmask interrupt
        TMR6IF = 0;

        // Count 250 ms from 10 ms micro ticks
        static uns8 count250ms;
        if ( ++count250ms == ( 250 / 10 ) )
        {
          // 250 ms
          count250ms = 0;

          // Pointer to the timers array
          FSR1 = (uns16)&Timers[0];
          // Output index
          static uns8 index;
          index = 0;
          do
          {
            // Is timer running (is non-zero)?
            if ( ( FSR1[1] | INDF1 ) != 0 )
            {
              // Get time
              static uns16 time;
              time.low8 = *FSR1++;
              time.high8 = *FSR1;
              // Is timer over?
              if ( --time == 0 )
                // Set output to OFF
                SetOutput( 0, index );

              // Store new time
              setINDF1( time.high8 );
              FSR1--;
              setINDF1( time.low8 );
            }
            // Next timer
            FSR1 += sizeof( Timers[0] );
            // Next index
          } while ( ++index < OUTPUTS_COUNT );
        }
      }
      return Carry;

      // -------------------------------------------------
    case DpaEvent_DpaRequest:
      // Called to interpret DPA request for peripherals
      // -------------------------------------------------
      // Peripheral enumeration
      if ( IsDpaEnumPeripheralsRequest() )
      {
        // We implement 1 standard peripheral
        _DpaMessage.EnumPeripheralsAnswer.UserPerNr = 1;
        FlagUserPer( _DpaMessage.EnumPeripheralsAnswer.UserPer, PNUM_STD_BINARY_OUTPUTS );
        _DpaMessage.EnumPeripheralsAnswer.HWPID = HWPID_IQRF_TECH__DEMO_BINARY_OUTPUT;
        _DpaMessage.EnumPeripheralsAnswer.HWPIDver = 0x0000;
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

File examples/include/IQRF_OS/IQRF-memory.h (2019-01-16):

// *****************************************************************************
//                               IQRF OS memory                                *
// *****************************************************************************
// Intended for:
//	 HW: TR-72D, TR-76D, TR-77D, TR-78D, TR-75D
//   OS: v4.03D
//
// Online IQRF OS Reference Guide: http://www.iqrf.org/IQRF-OS-Reference-guide/
//
// Copyright (c) IQRF Tech s.r.o.
//
// File:    IQRF-memory.h
// Version: v1.00                                   Revision: 15/03/2018
//
// Revision history:
//   v1.00: 15/03/2018  First release for OS 4.03D.
//
// *****************************************************************************

//******************************************************************************
// Temperature sensor configuration registers 
//******************************************************************************
typedef struct                                      // Default setting: 0b0000.0100
{
    bit resolution0;
    bit resolution1;
    bit powerDownMode;
    bit skipSetup;
} TmpCfg;                                           // For internal usage only

// *****************************************************************************
uns8  usedBank0[80]     @ 0x020;                    // Do not use this space
uns8  usedBank1[80]     @ 0x0A0;                    // Do not use this space
uns8  usedBank2[80]     @ 0x120;                    // Do not use this space
uns8  usedBank3[80]     @ 0x1A0;                    // Do not use this space
uns8  usedBank4[80]     @ 0x220;                    // Do not use this space
uns8  usedBank5[80]     @ 0x2A0;                    // Do not use this space
uns8  usedBank6[80]     @ 0x320;                    // Do not use this space
uns8  usedBank7[80]     @ 0x3A0;                    // Do not use this space
uns8  usedBank8[80]     @ 0x420;                    // Do not use this space
uns8  usedBank9[80]     @ 0x4A0;                    // Do not use this space
uns8  usedBank10[80]    @ 0x520;                    // Do not use this space
uns8  usedBank11[32]    @ 0x5A0;                    // Do not use 32B of bank11 (0x5A0 - 0x5BF)
// user space: bank11 48B (0x5C0 - 0x5EF) , bank12: 48B (0x620 - 0x64F)
#define UserBank_01     11
#define UserBank_02     12

//******************************************************************************
// Dedicated buffers and file registers
//******************************************************************************
uns8    bufferINFO[64]  @ usedBank6;				// Auxiliary buffer, 64B long
uns8    bufferCOM[64]   @ usedBank7;				// Buffer for communication routines, 64B long
uns8    bufferAUX[64]   @ usedBank8;				// Auxiliary buffer, 64B long
uns8    bufferRF[64]    @ usedBank9;				// Buffer for RF routines, 64B long

uns8	X70[16]			@ 0x70;			            // Register array in shared bank for user application
uns8 	userReg0		@ X70;			            // User's register in all banks
uns8 	userReg1		@ X70[1];		            // User's register in all banks
uns8 	RFmodeByte      @ X70[2];		            // Current RF mode !!! Read Only !!!
uns8 	param2			@ X70[3];		            // Parameter_01 for function calls
uns16 	param3			@ X70[4];		            // Used as parameter for function calls
uns16 	param4			@ X70[6];		            // Used as parameter for function calls
uns8 	bitmapBitMask	@ X70[12];					// Bit mask from addressBitmap function
uns8 	bitmapByteIndex	@ X70[14];					// Byte index from addressBitmap function
uns8 	userInterface	@ X70[15];					// See below !!! Read Only !!!	

// Network params !!! Read Only !!!
bank11 uns8  ntwADDR            @ usedBank11[0x00]; // Network address
bank11 uns8  ntwVRN             @ usedBank11[0x01]; // VRN
bank11 uns8  ntwZIN             @ usedBank11[0x02]; // Zone index
bank11 uns8  ntwDID             @ usedBank11[0x03]; // Discovery ID
bank11 uns8  ntwPVRN          	@ usedBank11[0x04]; // Parent VRN
bank11 uns16 ntwUSERADDRESS     @ usedBank11[0x05]; // For internal usage only
bank11 uns16 ntwID              @ usedBank11[0x07]; // Network identification (NID0/NID1)
bank11 uns8  ntwVRNFNZ          @ usedBank11[0x09]; // For internal usage only
bank11 uns8  ntwCFG			    @ usedBank11[0x0A]; // Network configuration
//
bank11 uns8 memoryOffsetFrom    @ usedBank11[0x0B]; // Offset for copying buffers
bank11 uns8 memoryOffsetTo      @ usedBank11[0x0C]; // Offset for copying buffers
bank11 uns8 userStatus          @ usedBank11[0x0D]; // Register cleared by OS after power-on reset but not after other reset types
bank11 uns8 toutRF              @ usedBank11[0x0E]; // Timeout for RFRXpacket duration
bank11 uns8 RFspeed             @ usedBank11[0x0F]; // Current RF speed !!! Read Only !!!
bank11 uns8 RFpower             @ usedBank11[0x10]; // Current RF power !!! Read Only !!!
bank11 uns8 RFchannel           @ usedBank11[0x11]; // Current RF channel !!! Read Only !!!
bank11 uns8 SPIpacketLength     @ usedBank11[0x12]; // SPI packet length !!! Read Only !!!
bank11 uns8 lastRSSI            @ usedBank11[0x16]; // RSSI of last receipt !!! Read Only !!!
bank11 uns8 configFRC           @ usedBank11[0x17]; // FRC configuration
bank11 uns8 sysReg1             @ usedBank11[0x1B]; // System register
//
bank11 uns8 responseFRCvalue    @ usedBank11[0x1C]; // FRC response value for 2 bits or 1 byte FRC
bank11 uns16 responseFRCvalue2B @ usedBank11[0x1C]; // Two bytes FRC response value
bank11 uns32 responseFRCvalue4B @ usedBank11[0x1C]; // Four bytes FRC response value (use .low8, .low16, .high16, ... to access this variable at the free CC5X edition)
//
bank5 uns8 FRCextraTime			@ usedBank5[0x49];	// Additional waiting time [ticks] for FRC response
bank5 uns8 bondingMask 			@ usedBank5[0x4E];	// Bonding mask for remote bonding
bank5 uns8 bondingCounter       @ usedBank5[0x4F];  // Bonding counter for remote bonding
//
bank3 TmpCfg tmpCfg             @ usedBank3[0x49];  // For internal usage only
bank3 uns16 CRC16               @ usedBank3[0x4A];  // For internal usage only
bank3 uns8 XLPticks             @ usedBank3[0x4C];  // Number of ticks remaining to end of XLP packet transmission
bank3 uns8 memoryLimit          @ usedBank3[0x4D];  // Limit for copying buffers
//
bank0 uns8 sysReg2              @ usedBank0[0x22];  // System register
//******************************************************************************
// After getStatusSPI() in param2 there are information as below
//******************************************************************************
bit _SPIRX             		    @ param2.3;         // Something received on SPI
bit _SPICRCok          		    @ param2.4;         // Received SPICRC (last one) was OK
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

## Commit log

2018-12-19 LED do
    [example-do.fzz]
2018-12-19 hall sensor example
    [example-hall.fzz]
2018-12-27 exa web
    [example-di.fzz, example-do.fzz, example-ePir.fzz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]
2019-01-05 updated docs
    [example-standardBinOutput.fzz]
2019-01-06 docs update
    [example-standardLight.fzz]
2019-01-08 Photoresistor and thermistor examples.
    [example-standardPhotorezistor.fzz, example-standardThermistor.fzz]
